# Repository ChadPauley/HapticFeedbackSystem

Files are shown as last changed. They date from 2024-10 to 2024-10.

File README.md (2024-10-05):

The purpose of this directory is to store PCB work and documentation on my first PCB design that was developed and sent to a fab house. While working on a team, I was tasked with designing the PCB layout for a Carrier Board that houses a CM4 module.
There are three versions of the PCB as we discovered issues and misleading information in the CM4 documentation such as camera pin layout. The final version worked and is in the primary CAD and schematic directory.

Version 2:
I2C lines for CAM1 are used for CAM0 which makes the camera a little finicky.

Version 3:
V3 fixes the issue with the camera and acts as a more ideal PCB.
--------------------------------------------------------------------------

After this project I have begun to focus more on the KiCAD software to design PCB fabs as a hobby due to the limitations of EAGLE only allowing 2 layers for the free version.

--------------------------------------------------------------------------
Real Fab Shape/Size:
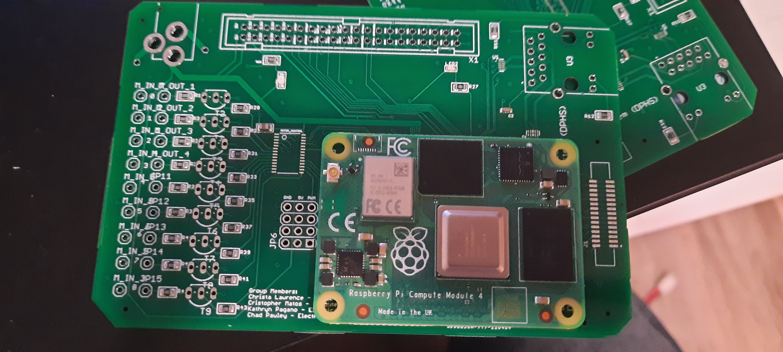
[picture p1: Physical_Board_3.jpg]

--------------------------------------------------------------------------
CAD Layout:
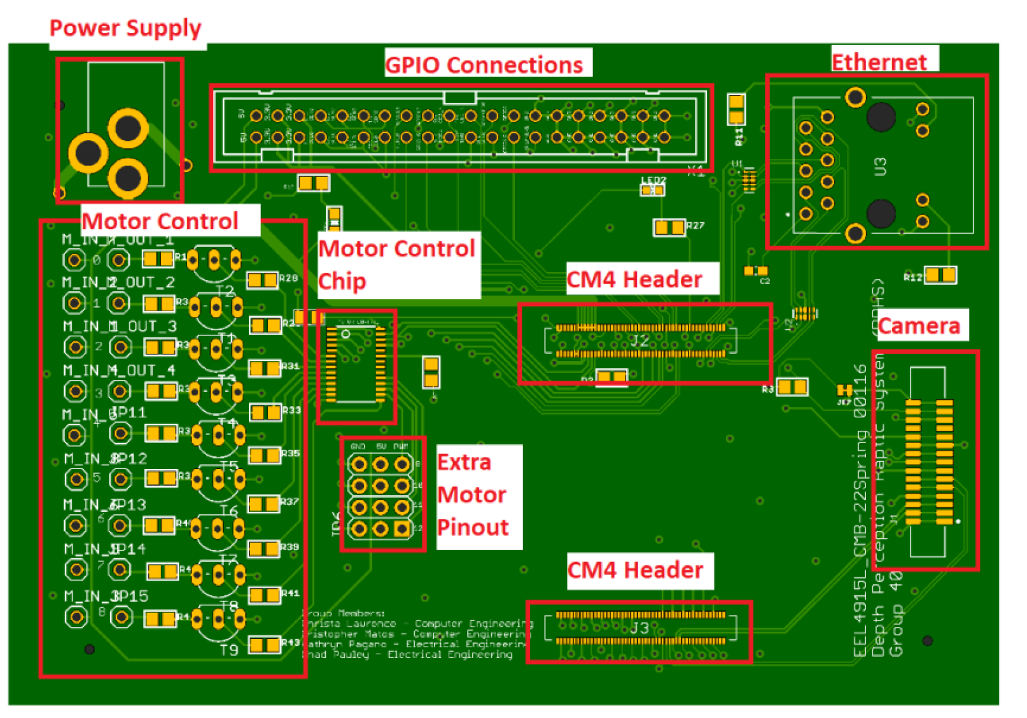
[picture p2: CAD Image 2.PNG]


--------------------------------------------------------------------------
Net paths:
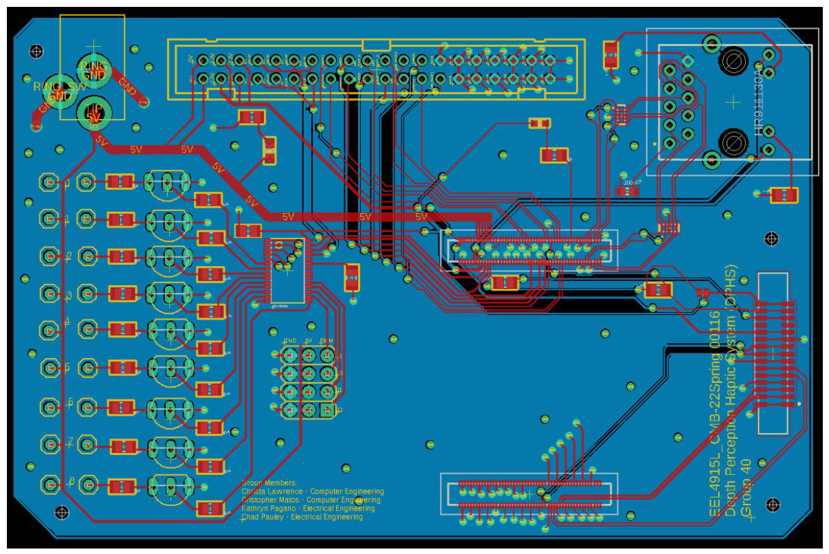
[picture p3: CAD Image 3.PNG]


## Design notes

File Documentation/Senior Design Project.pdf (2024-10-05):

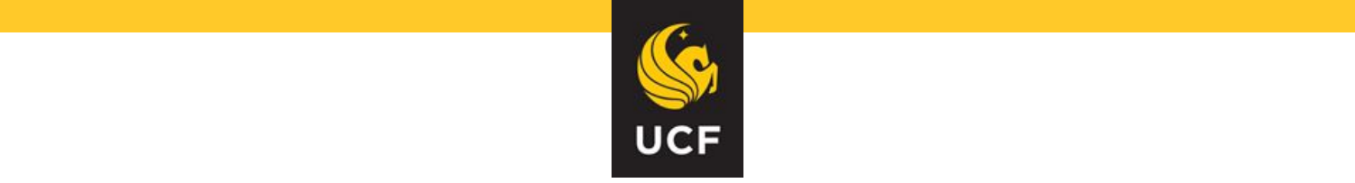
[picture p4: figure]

# Depth Perception Haptic System

# Group 40

## Christa Lawrence CpE Cristopher Matos CpE, Psych Kathryn Pagano EE Chad Pauley EE

# Outline

## - Goals and Requirements

## - Hardware Discussion and Component Considerations

## - Software Discussion

## - Successes and Difficulties

## - Administrative Details

# Goals

## - Wearable device that allows for hands-free navigation of indoor and outdoor

## spaces for people with impared vision

## - In particular:

- Avoid large obstacles (e.g., walls, poles, trash cans)

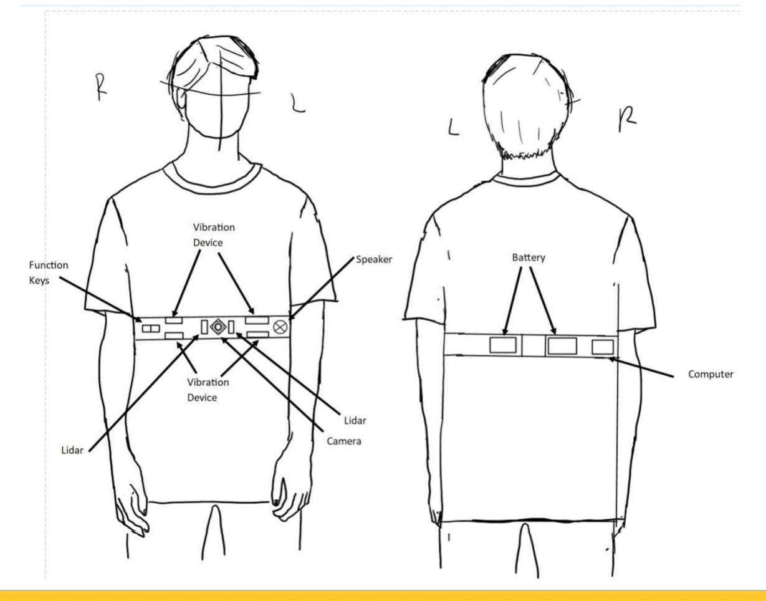
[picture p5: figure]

- Properly respond to sidewalk curbs

# Requirement Specifications

Statement | Description | Value | Unit
Lightweight | Total weight of electronics, housings, and cloth. | < 10 | lb
Compact | Thickness along all axes normal to the body. | < 2 | in
Full Range of Motion (ROM) | ROM of shoulder joints before and after putting on device. | < 10 | % diff
Large Buttons | Surface area large enough to contain braille. | > 0.7 | in²
Long Lasting, Rechargeable Battery | Time from full charge to depletion at 80% feedback level and all sensors active. | > 4 | hrs
Haptic feedback that encodes distance | Provides a relative indication of distance (via feedback intensity) of arbitrarily shaped objects visible to the camera over a discrete range of intensities (including zero). | ≥ 3 | ct
Alert to proximal objects | Objects near the device trigger an unambiguous alert. | < 3 | ft
Quick Response Time | Time it takes for the device to send a haptic response from
a spontaneously appearing obstacle.

< 900 ms

# Goals

Category | Goals
Physical Attributes | Lightweight, compact, durable
Usage & Maintenance | Responsive, rechargeable, long battery life, full range of motion (ROM)
User Interface | Simple, accessible, quick to learn
General Navigation | Encode distance and location of obstacles, alert to emergencies
Outdoor Navigation | Detect and describe curb presence, orientation, and magnitude

# Solution Approach - Obstacle Avoidance

## - Combine computer vision with LiDAR to map objects in the environment to

## the user’s body via haptic (vibration) feedback

- Minimizes # of sensors, maximizes input data

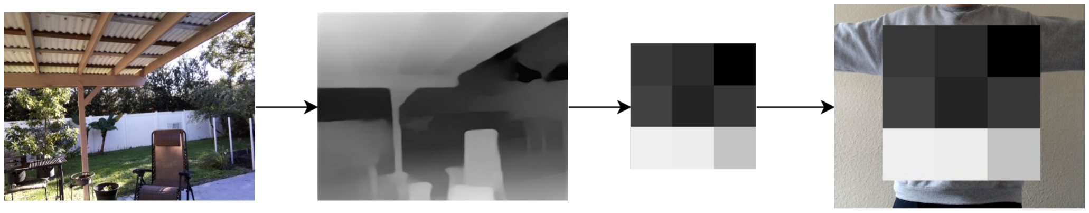
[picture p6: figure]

# Overall Block Diagram

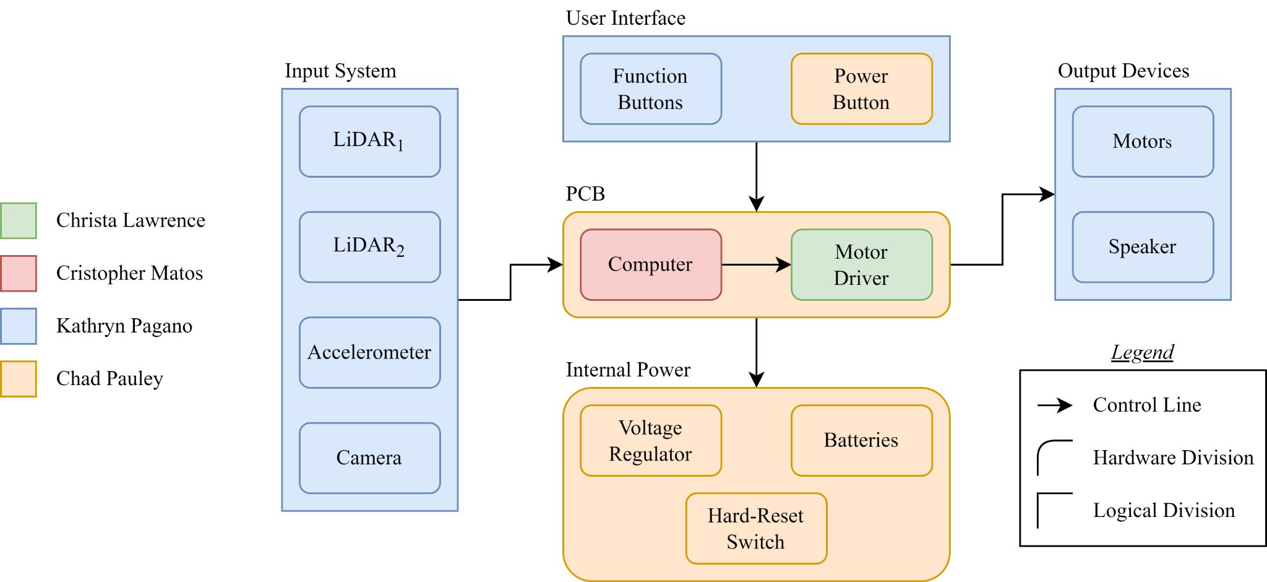
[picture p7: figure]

# Hardware Design Approach

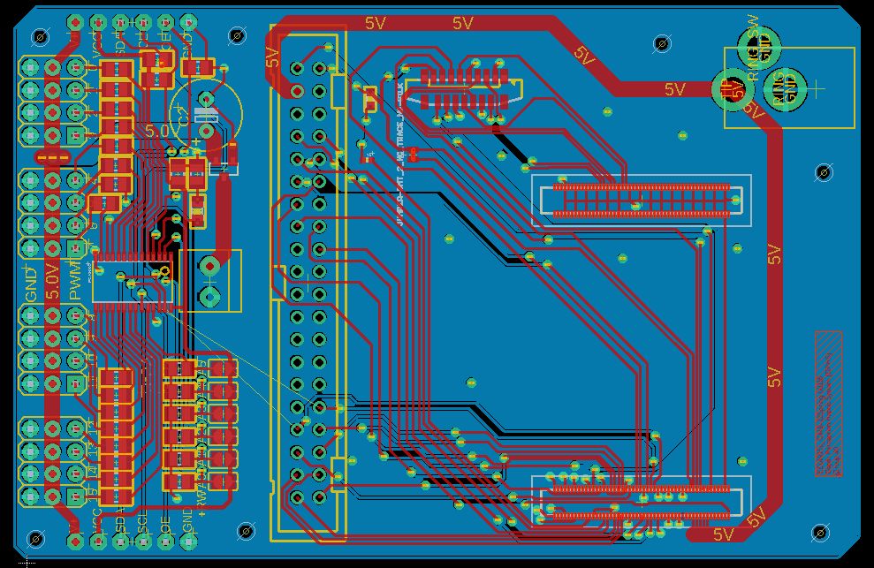
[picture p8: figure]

## Design Considerations

## - Minimize power consumption - Low resolution output - Minimize number of sensor units while

maximizing input data (CV + LiDAR),

## - Ensuring all clock and input data is coherent - Enough outputs to ensure future development and testing potential

Always plan to make a prototype, because you’ll end up building one anyway

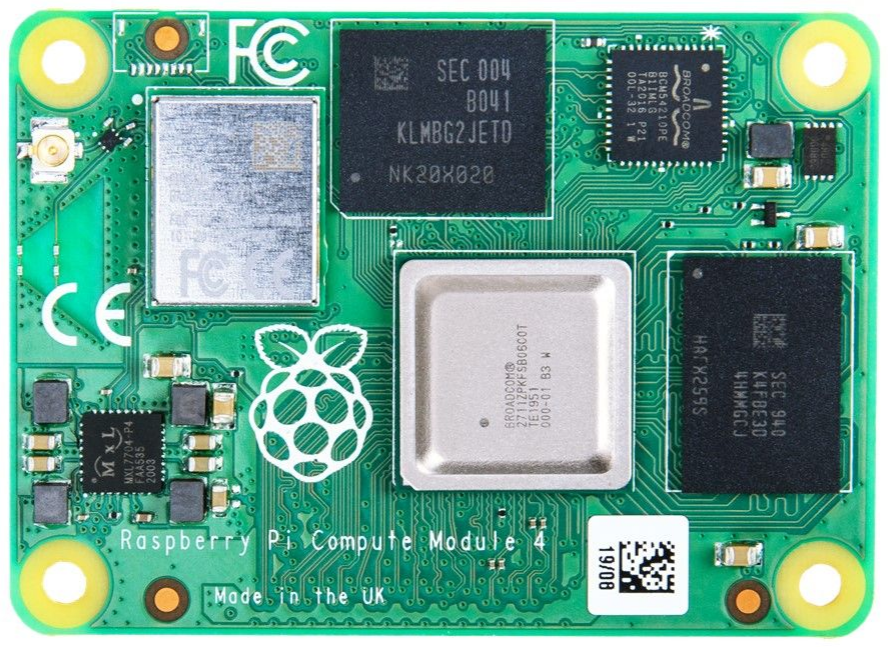
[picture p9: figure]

# Major Component Considerations

## - Raspberry Pi Compute Module 4 (CM4)

- Price
- Hardware independence
■ Entire project run on ARM CPU (and integrated GPU)
- Required RAM and embedded memory
- Availability of schematics
- Ability to modify carryout board
- GPIO availability (up to 5x UART, 5x I2C, 1x SDIO, 1 PCM, 2x PWM, 3x GPCLK, two MIPI CSI channels and multiple voltage output lanes including 3.3V and 1.8V)

# Raspberry Pi Camera

Model:Raspberry Pi Camera Module 2 Resolution
- 8-megapixel
- 3280 x 2464 still frame
Video mode
- 1080p30, 720p60, 480p90
Price
- $25.00
Board size
- 23.86 x 25 x 9mm
Onboard processor
- No

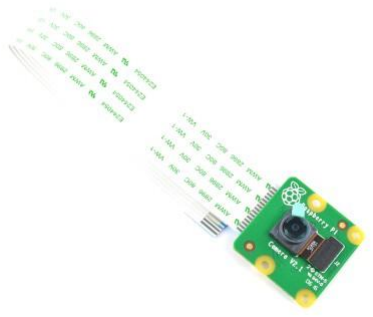
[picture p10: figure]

The camera module is incredibly small and can easily be concealed.
This camera is compatible with the Raspberry Pi board and can be connected using either a 15 pin connector or 22 pin adapter ribbon to work with the board.
It uses the Camera Serial Interface Type 2 (CSI-2).
Software Controlled directly by board, no special drivers needed.

# PCB Housing

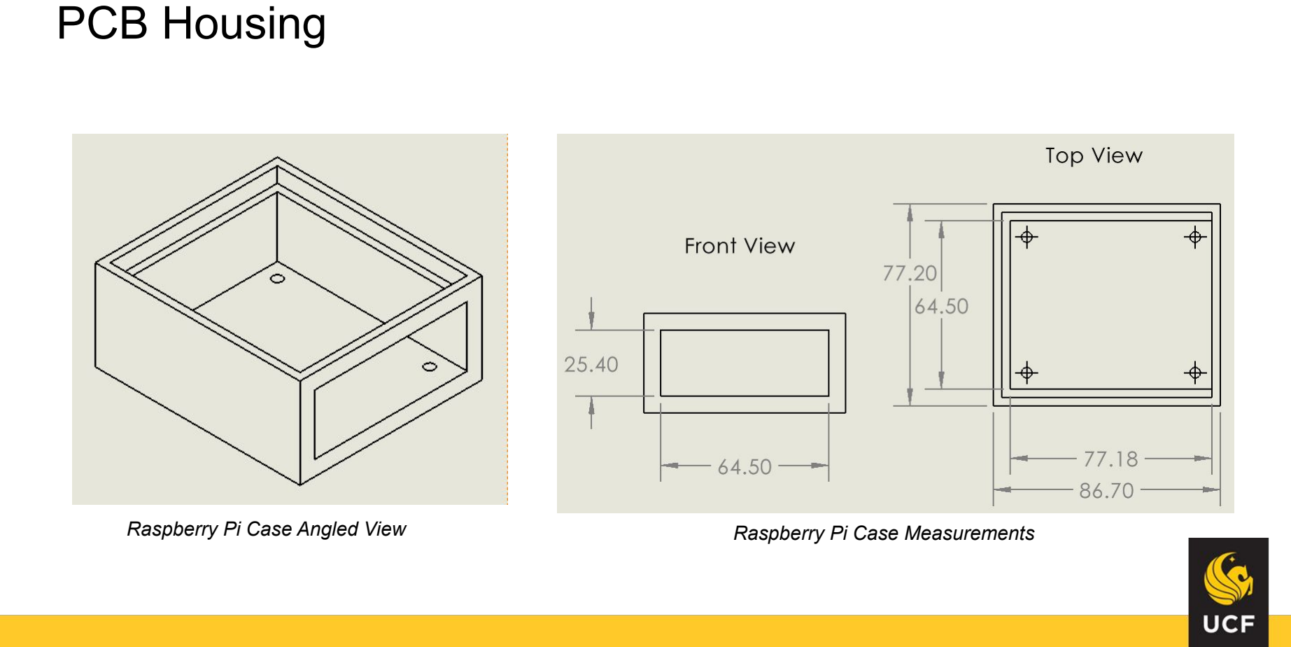
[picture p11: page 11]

Raspberry Pi Case Angled View | Raspberry Pi Case Measurements

# Raspberry Pi Camera Case

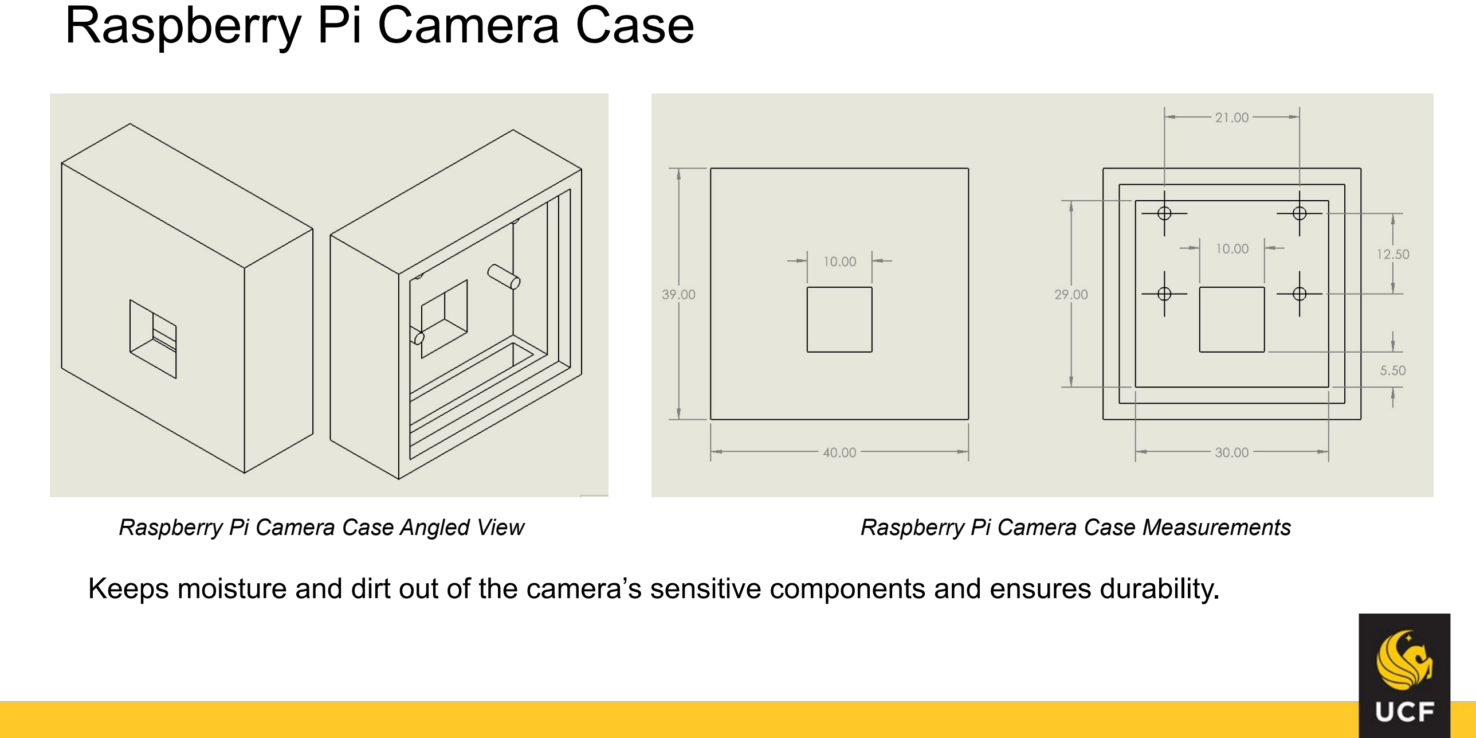
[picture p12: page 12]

Keeps moisture and dirt out of the camera’s sensitive components and ensures durability.

Raspberry Pi Camera Case Angled View | Raspberry Pi Camera Case Measurements

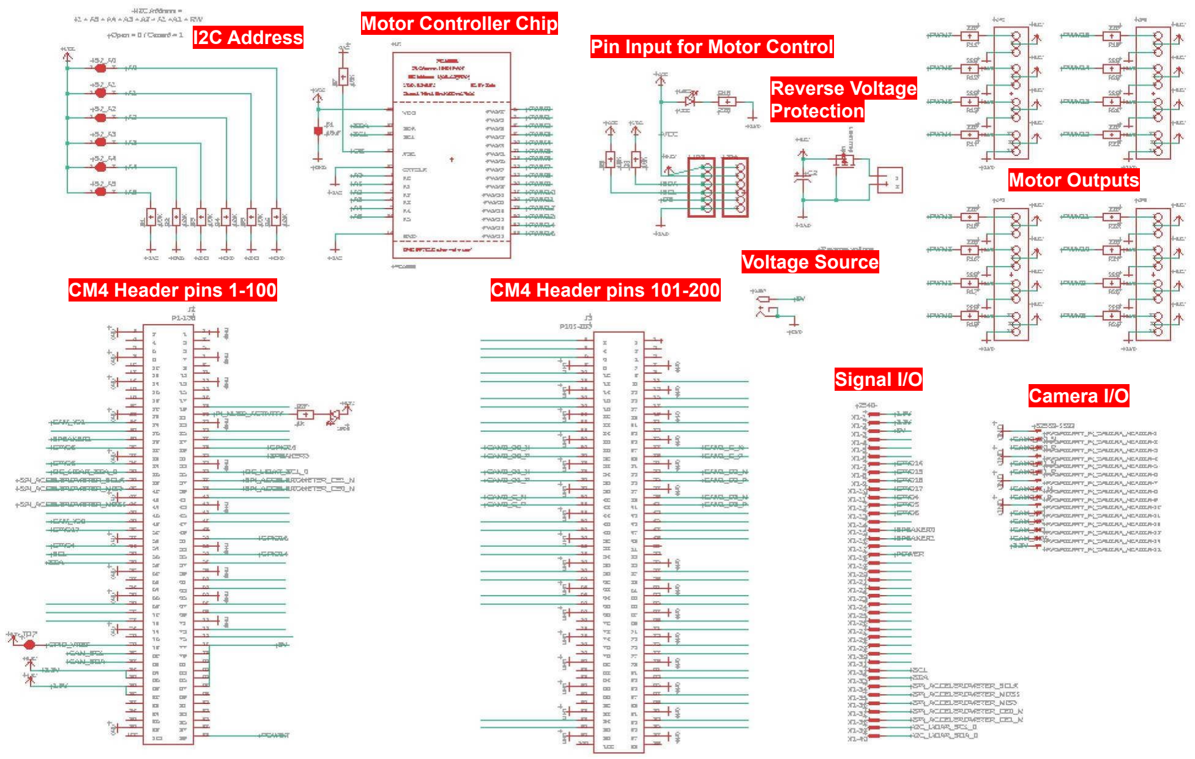
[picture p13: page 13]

Motor Controller Chip I2C Address | Pin Input for Motor Control

Voltage Source

Reverse Voltage
Protection

Motor Outputs

CM4 Header pins 1-100 | CM4 Header pins 101-200

Signal I/O
Camera I/O

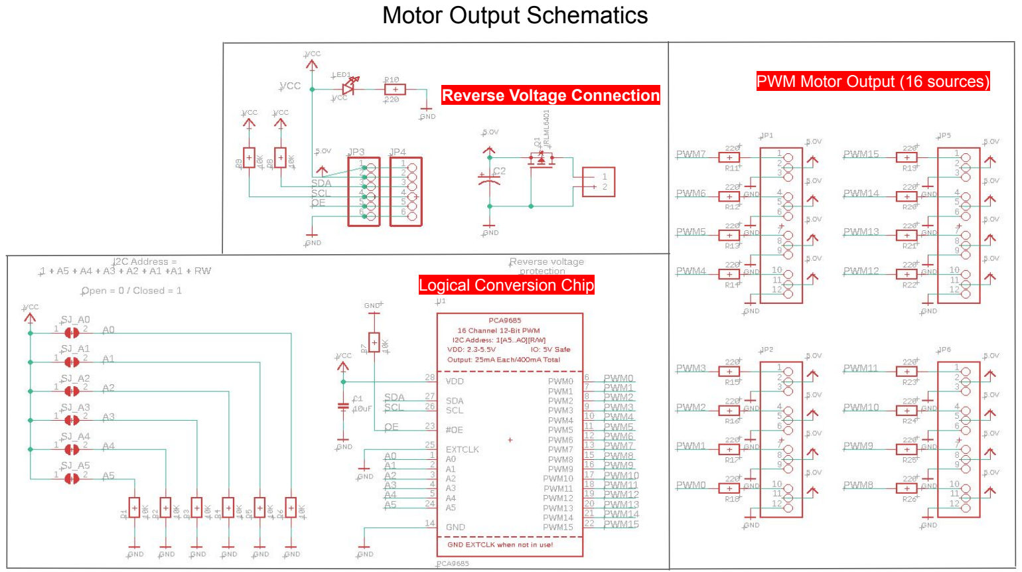
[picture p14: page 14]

Logical Conversion Chip

PWM Motor Output (16 sources) Reverse Voltage Connection

Motor Output Schematics

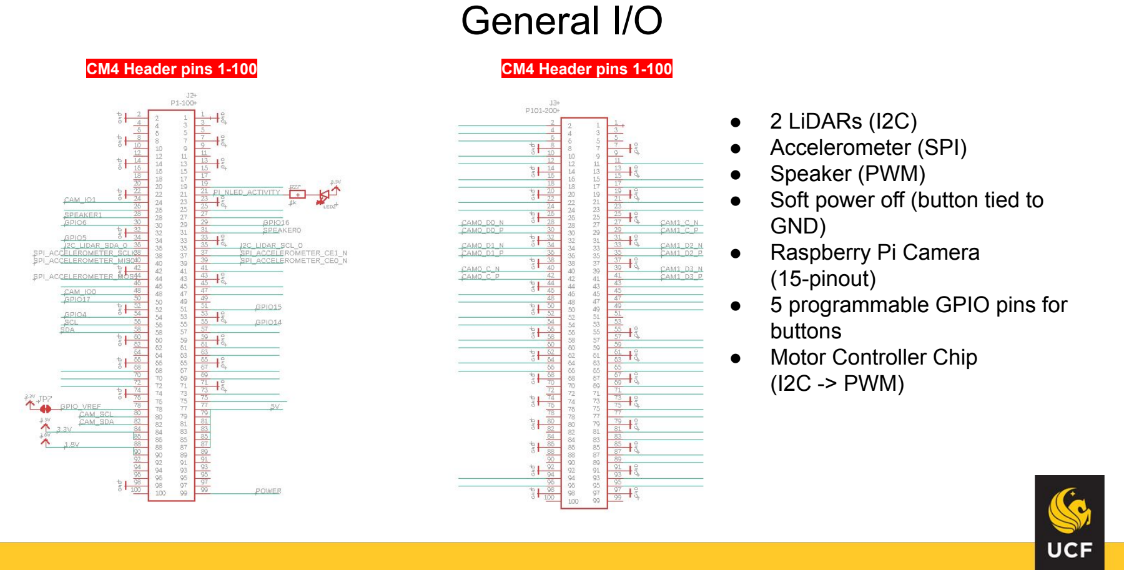
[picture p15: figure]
General I/O; ● 2 LiDARs (I2C) ● Accelerometer (SPI) ● Speaker (PWM) ● Soft power off (button tied to GND) ● Raspberry Pi Camera (15-pinout) ● 5 programmable GPIO pins for buttons ● Motor Controller Chip (I2C -> PWM)

CM4 Header pins 1-100 | CM4 Header pins 1-100

# Board layout

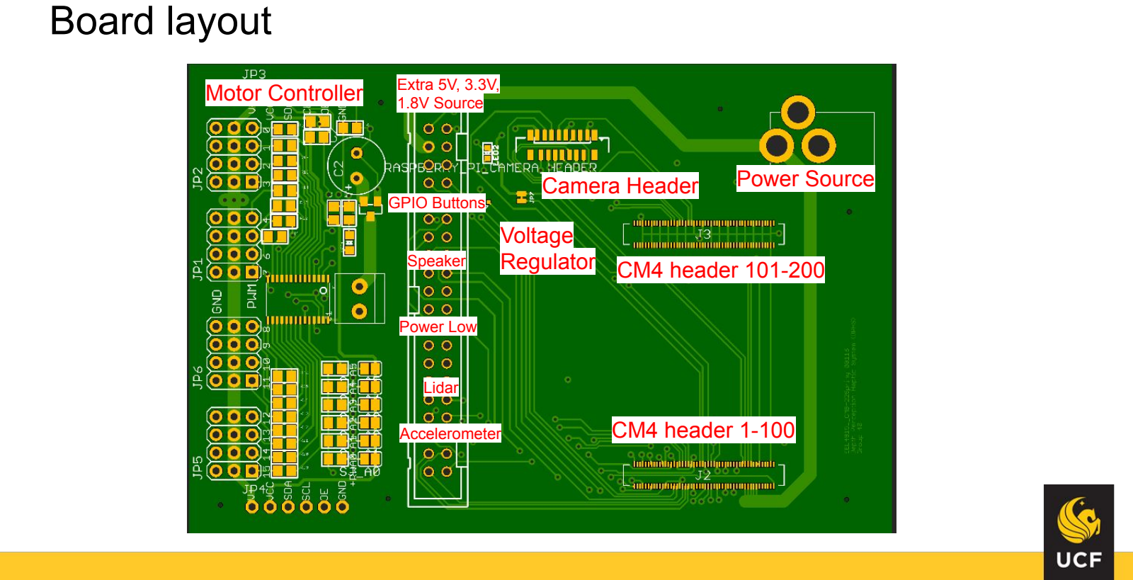
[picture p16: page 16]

Power Source

CM4 header 101-200

CM4 header 1-100

Camera Header

Voltage
Regulator

Motor Controller Extra 5V, 3.3V, 1.8V Source

GPIO Buttons

Speaker

Power Low

Lidar

Accelerometer

# 5 Programmable Buttons

## 1) Resting mode 2) Reset device due to error 3) Pathway Finder 4) Lower level of vibration 5) Increase level of vibration

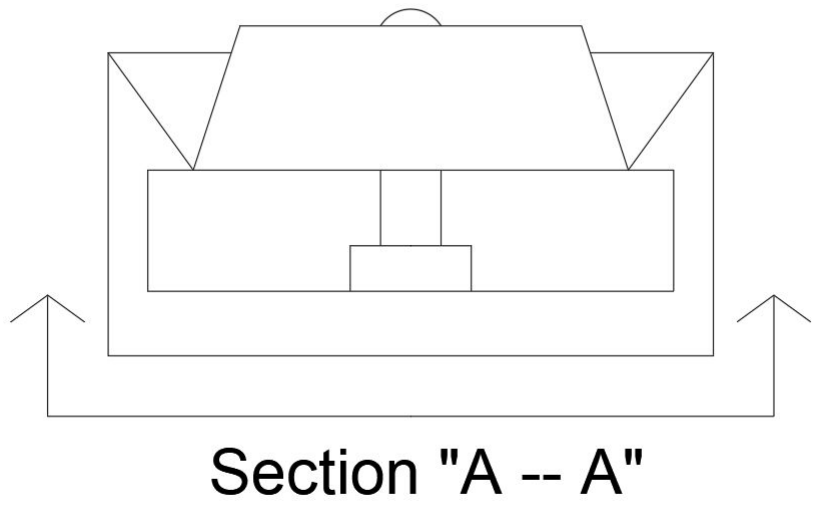
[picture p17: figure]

Button Cross-section

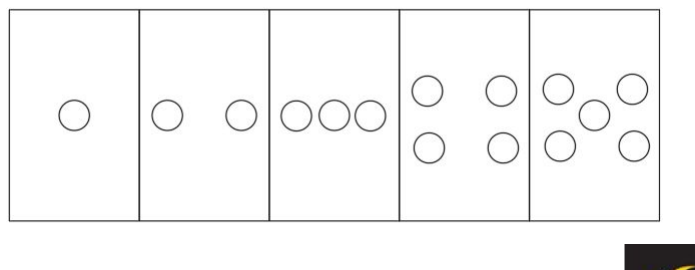
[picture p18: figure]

Button Domino Pattern

# Three Levels of Power Control

## - Idle Power Off (Software Controlled)

- Controlled by accelerometer input value and determination by CM4; the device will go into a resting mode reducing power usage to a minimal amount (around 8mA).

## - Button Power Off (Software Controlled)

- Button connected to GPIO GLOBAL_EN set driven low sets device to minimum power usage (around 15μA).

## - Switch Power Off (Hardware Controlled)

- Physical switch between the batteries and voltage regulator to allow the batteries and device to maintain longevity as well as function as hard reset for any potential errors.

# Voltage Regulator

## Batteries will be wired in parallel to provide the longest battery longevity possible

and allowing the device to maintain a steady current in the device for any needs.

## Mounted separately to batteries to have 5V source instead of 9V+. This prevents the user from getting shocked or burned by the device when the user is sweating

and the overall concern of the wear and tear of the device.

## A TAMAYA plug or Barrel Power Jack will be used to charge the device (as shown

below). User preference will be noted in a future study.

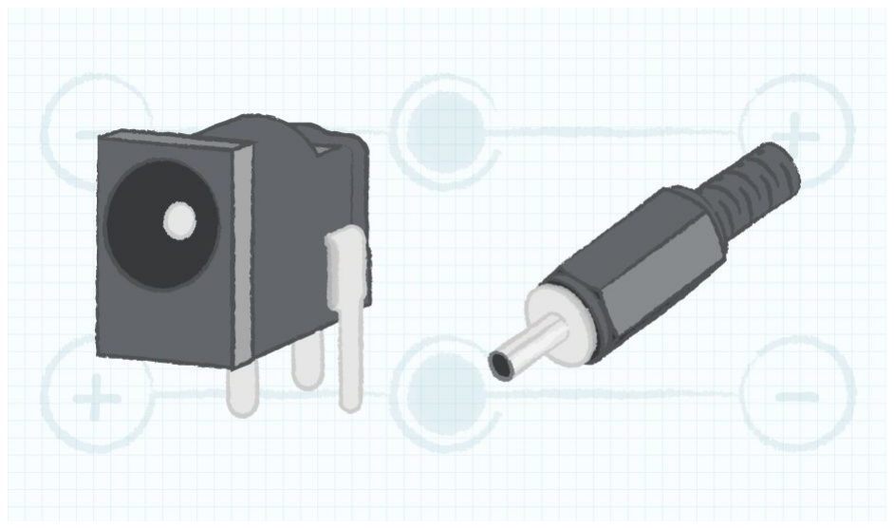
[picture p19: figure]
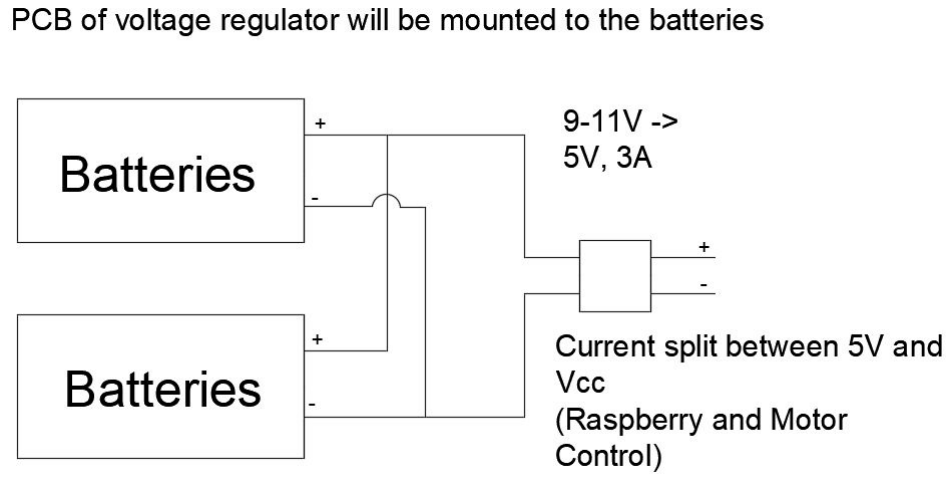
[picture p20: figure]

# Power Considerations

- Battery must be able to supply 3A with a voltage source between 5V and 30V.
- Due to design constraints in creating a power bus; the power for the CM4 and PWM motor control are differentiated as a primary 5V pin and VCC pin respectively on the board to evenly split current and effectively half the needed width for the bus channels on the PCB.

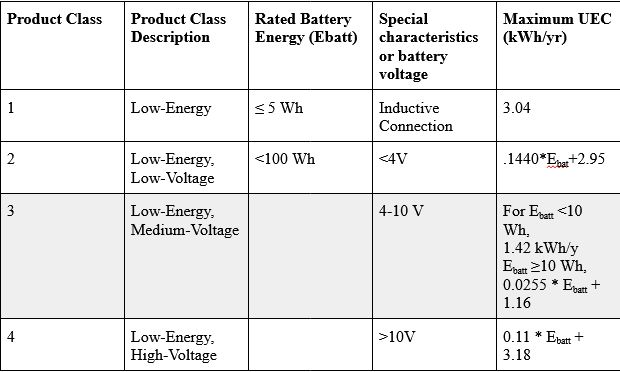
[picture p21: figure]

Electronic Code of Federal Regulations
- The device must be less than or equal to the maximum unit of energy consumption (UEC) for the appropriate product class and battery rating

# Hardware Design Changes Made Over Time

- Removal of HDMI interface as later noted as unnecessary and to reduce size of PCB - Removal of SD memory storage due to the need for more GPIO pins - Removal of voltage regulator chip on primary PCB board due to concern of electric shock - Change from using PWM with MOSFET connection which would control voltage of haptic motors with duty cycle to a direct connection with a simple diode and capacitor controlled by the programmable values set by analog

# Software Block Diagram

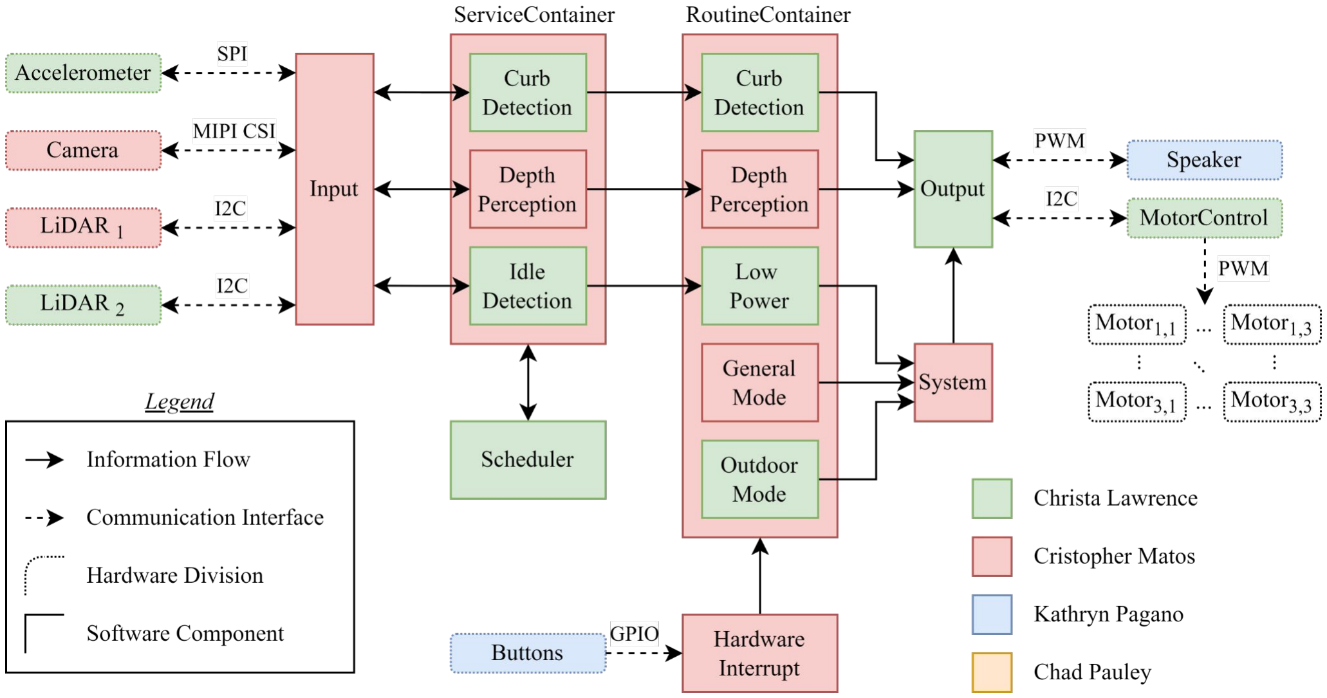
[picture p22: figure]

# Depth Sensing Approach

## - Problem: Need distances of objects located in front of the user

- Existing products use:
■ | Multiple distance sensors placed along body
■ | One distance sensor, actively manipulated by user
- Conflicts with our goals:
■ | Few sensors (For full ROM and comfort)
■ | Hands-free operation

## - Solution: Combine computer vision (CV) with LiDAR to estimate depth

# Depth Sensing Approach Motivation

## - Explosion of research and development in monocular depth estimation for mobile devices (Ignatov et al., 2021)

- Some models (including MIT Licensed) already exist online

## - Prospect of combining depth inferencing with LiDAR

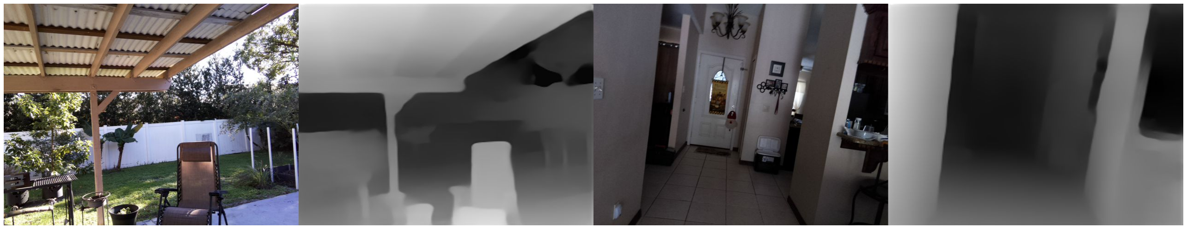
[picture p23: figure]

## Inference using Intel’s Midas/v2_1_small on TensorFlow Lite

# Depth Sensing Procedure

## 1. Use CV to create a depth map of the space in front of the user

a. LiDAR used to approximate true values

## 2. Divide map into regions 3. Find one representative value per region 4. Set motor intensity based on value

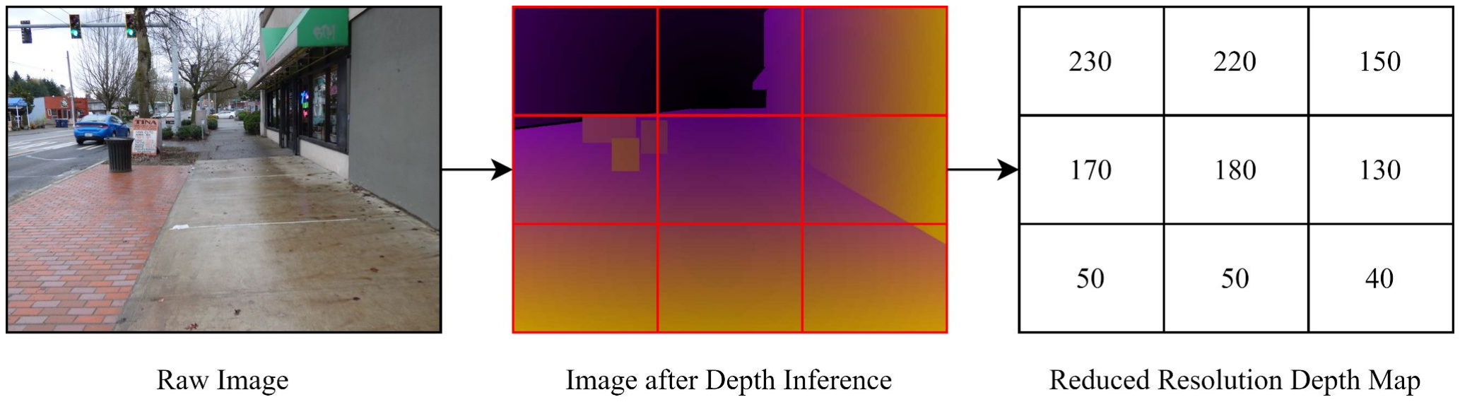
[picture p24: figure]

## Raw Image sourced from (SDOT, 2015)

# Depth Sensing Problems

## - Inference time (exposed chip, no fan, 21℃, all on CPU)

- Arithmetic Mean: 912 ms, Sample Std Dev: 11 ms, Maximum: 967 ms

## - Temperature

- Throttle temperature reached within 700 iterations (~ 12 mins)

# Depth Sensing Solutions Considered

## - NVIDIA Jetson Nano?

- 2x Price
- Research shows ARM CPU is all that is needed for fast depth estimation

## - Overclocking CPU?

- Energy consumption and device lifetime
- Intended to operate over several hours

## - Start from scratch?

- Lack time and resources to train robust model
- Models tend to underperform on datasets not used in training/validation (Ranftl et al., 2020)

## - Another pretrained model?

- MIT Licensed models tested significantly slower (seconds)

# Depth Sensing Solutions

## - Quantization and Open-Source Optimization tools - Knowledge distillation

- Use representative dataset to train new model with Midas as teacher
- Some approaches show inference time as low as 97 ms (Zhang et al., 2021)

## - On-board GPU acceleration

- Some libraries available (beatmup, ncnn)

## - Introduce a heat sink - Worst-case scenario: Forfeit robustness for speed

- Train new model on a subset of datasets

# Other Software

## - Curb Detection

- Use a LiDAR unit angled downward to determine magnitude and direction of curbs

## - Idle Detection

- Accelerometer used to estimate velocity of user

## - Speaker announces mode changes, power-on, power-off, and emergencies - Buttons control mode of system

# Successes and Difficulties

## Part Availability (Voltage Regulators)

## Shipping Dates

## PCB arrangement on 2-layer design

## CV Runtime Reduction

# Budget

Item Type | Quantity | Actual Cost | Description
LiDAR | 2 | $59.99 | Garmin LiDAR
Accelerometer | 1 | $18.95 | ADXL345
Camera | 1 | $25 | Raspberry Pi Camera
Speaker | 1 | $10.69 | MakerHawk Speaker
Haptic feedback | Set acquirement (20) | $16.04 | Tatoko flat coin motors
Compute Module | 1 | $65 | Raspberry Pi Compute 4 Module 4GB
Shipping | | $37.93 | Shipping on parts
Current Total (As of 11/19/2021) | | =293.60

# Progress by Category

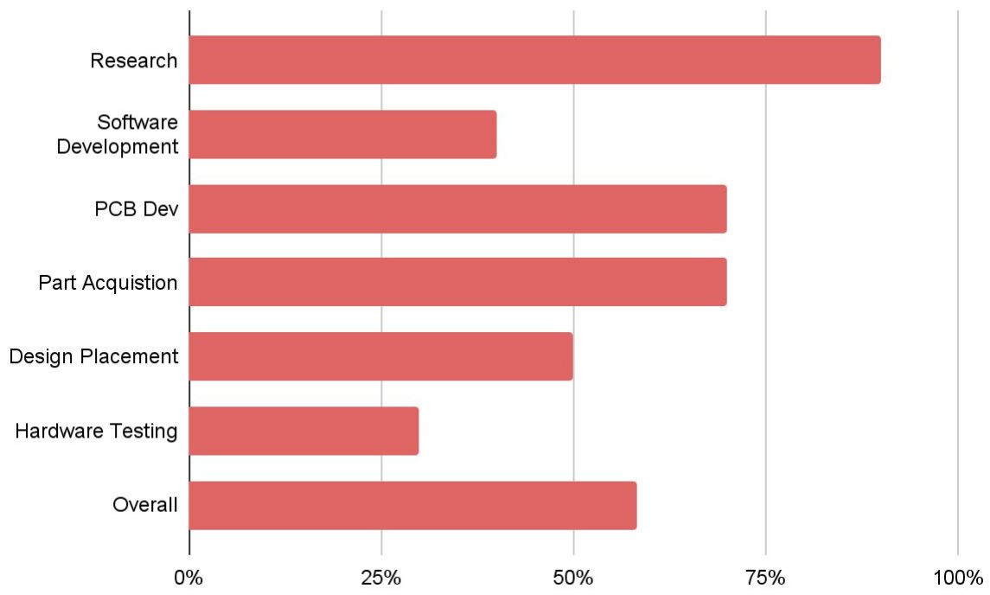
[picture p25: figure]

# Steps Toward Completion - Software

Step | Deadline
Faster (< 900 ms) depth estimation on RPi4 Faster (< 500 ms) depth estimation on RPi4 | February 27 March 13
UI, general mode, outdoor mode code complete | March 6
Idle detection, lower power mode, speaker code complete | March 20
Initial software testing and refactoring complete | April 3
Final software testing and optimization complete | April 10

# Steps Toward Completion - Hardware

Step | Deadline
User interface constructed, tested All devices integrated in development environment | March 6
PCB final version submitted | March 20
All devices integrated in fully functional prototype | April 3
Assembly of final project complete | April 10

# Milestones

Milestone | Due Date
Basic end-to-end functionality (CV + LiDAR integration, motor output) | February 25
Full initial prototype (buttons, all functionalities, motor output, improved CV performance, battery connection) | March 13
Final prototype complete (fully functional vest) | April 3
Final testing and optimization complete | April 10

# Progress Photos

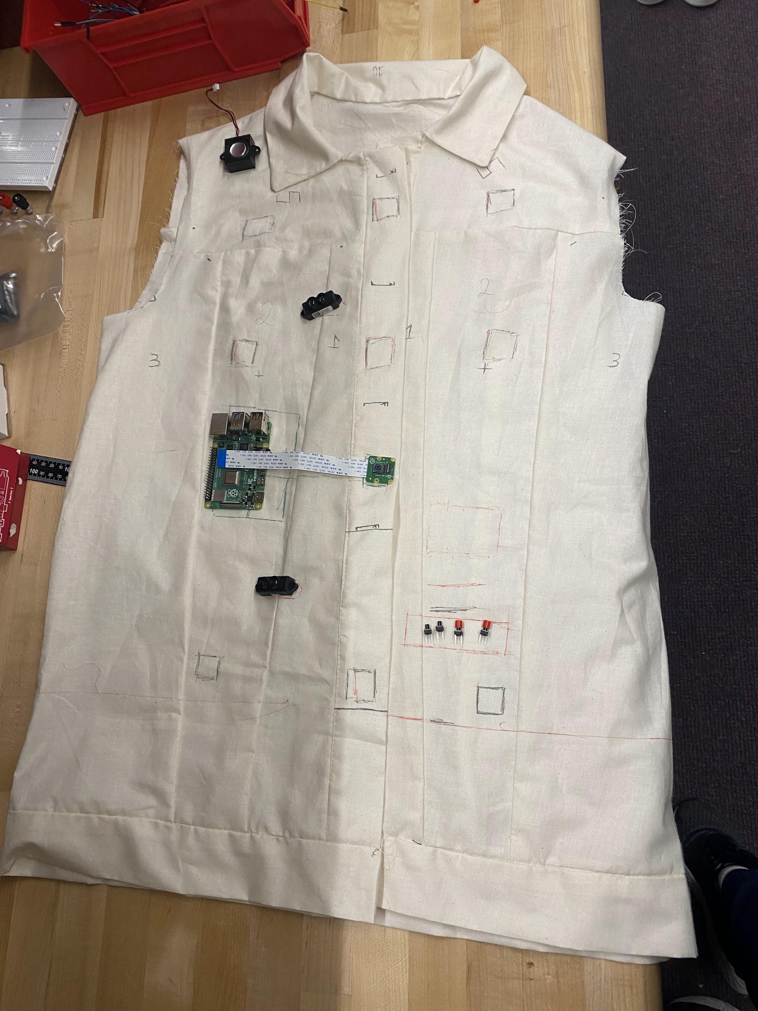
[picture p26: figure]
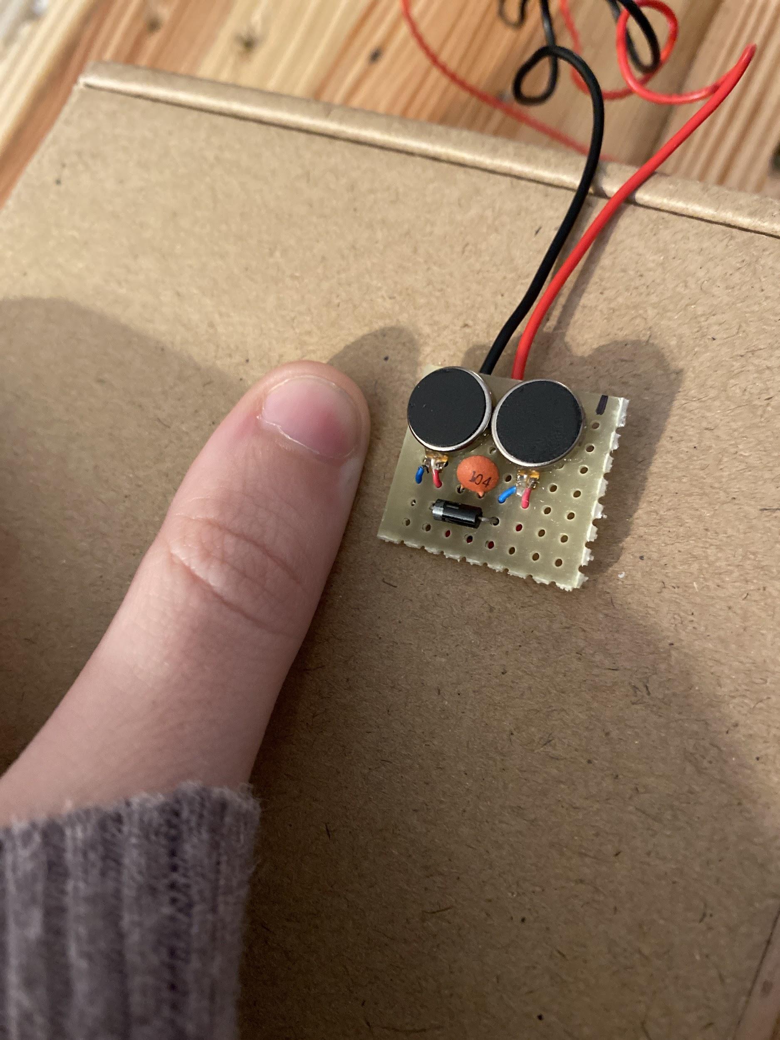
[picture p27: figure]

# References

Allan, Alasdair. “Benchmarking TensorFlow Lite on the New Raspberry Pi 4, Model B.” Hackster.io, 2019, https://www.hackster.io/news/benchmarking-tensorflow-lite-on-the-new-raspberry-pi-4- model-b-3fd859d05b98.

Ignatov, Andrey, et al. “Fast and Accurate Single-Image Depth Estimation on Mobile Devices, Mobile AI 2021 Challenge: Report.” ArXiv, 17 May 2021, https://arxiv.org/pdf/2105.08630.pdf.

Ranftl, Rene, et al. “Towards Robust Monocular Depth Estimation: Mixing Datasets for Zero-shot Cross-dataset Transfer.” IEEE Transactions on Pattern Analysis and Machine Intelligence, 2020, https://arxiv.org/abs/1907.01341.

SDOT Photos. “Columbia City Sidewalk Repair Project.” flickr, 16 Dec. 2015, https://www.flickr.com/photos/sdot_photos/23168490614. Image. Used in its resized form, and colored over with gradients to depict depth. Licensed under CC BY-NC 2.0.

Zhang, Ziyu, et al. “A Simple Baseline for Fast and Accurate Depth Estimation on Mobile Devices.” 2021 IEEE/CVF Conference on Computer Vision and Pattern Recognition Workshops (CVPRW), 2021, https://openaccess.thecvf.com/content/CVPR2021W/MAI/papers/Zhang_A_Simple_Baseline_for_Fast_and_Accurate_Depth_Estimation_on_CVPRW_2021_paper.pdf.

# Questions?

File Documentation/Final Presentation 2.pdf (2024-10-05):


# Depth Perception Haptic System

# Group 40

## Christa Lawrence CpE Cristopher Matos CpE, Psych Kathryn Pagano EE Chad Pauley EE

# Outline

## - Project Objective

## - Requirements

## - Software Discussion

## - Hardware Discussion

## - Administrative Details

## - Testing

## - Demonstration

# Project Objective

## The Depth Perception Haptic System

## is a wearable device that allows for

## hands-free navigation of indoor and

## outdoor spaces

# Goals

Category | Goals
Physical Attributes | Lightweight, compact, durable
Usage & Maintenance | Responsive, rechargeable, long battery life, full range of motion (ROM)
User Interface | Simple, accessible, quick to learn
General Navigation | Encode distance and location of obstacles, alert to emergencies
Outdoor Navigation | Detect and describe curb presence, orientation, and magnitude

# Requirement Specifications

Statement | Description | Value | Unit
Lightweight | Total weight of electronics, housings, and cloth. | < 10 | lb
Compact | Thickness along all axes normal to the body. | < 2 | in
Full Range of Motion (ROM) | ROM of shoulder joints before and after putting on device. | < 10 | % diff
Large Buttons | Surface area large enough to contain braille. | > 0.25 | in²
Long Lasting, Rechargeable Battery | Time from full charge to depletion at 80% feedback level and all sensors active. | > 6 | hrs
Haptic feedback that encodes distance | Provides a relative indication of distance (via feedback intensity) of arbitrarily shaped objects visible to the camera over a discrete range of intensities (including zero). | ≥ 3 | ct
Alert to proximal objects | Objects near the device trigger an unambiguous alert. | < 3 | ft
Quick Response Time | Time it takes for the device to send a haptic response from
a spontaneously appearing obstacle.

< 900 ms

# Solution Approach - Obstacle Avoidance

## - Combine computer vision with LiDAR to map objects in the environment to

## the user’s body via haptic (vibration) feedback

- Minimizes # of sensors, maximizes input data


# Overall Block Diagram


# Hardware Design Approach


## Design Considerations

## - Minimize power consumption - Low resolution output - Minimize number of sensor units while

maximizing input data (CV + LiDAR),

## - Ensuring all clock and input data is coherent - Enough outputs to ensure future development and testing potential

Always plan to make a prototype, because you’ll end up building one anyway


# Major Component Considerations

## - Raspberry Pi Compute Module 4 (CM4)

- Price
- Hardware independence
■ Entire project run on ARM CPU (and integrated GPU)
- Required RAM and embedded memory
- Availability of schematics
- Ability to modify carryout board
- GPIO availability (up to 5x UART, 5x I2C, 1x SDIO, 1 PCM, 2x PWM, 3x GPCLK, two MIPI CSI channels and multiple voltage output lanes including 3.3V and 1.8V)

# Raspberry Pi Camera

Model:Raspberry Pi Camera Module 2 Resolution
- 8-megapixel
- 3280 x 2464 still frame
Video mode
- 1080p30, 720p60, 480p90
Price
- $25.00
Board size
- 23.86 x 25 x 9mm
Onboard processor
- No
The camera module is incredibly small and can easily be concealed.
This camera is compatible with the Raspberry Pi board and can be connected using either a 15 pin connector or 22 pin adapter ribbon to work with the board.
It uses the Camera Serial Interface Type 2 (CSI-2).
Software Controlled directly by board, no special drivers needed.

# PCB Housing


Raspberry Pi Case Angled View | Raspberry Pi Case Approx. Measurements

# Raspberry Pi Camera Case


Keeps moisture and dirt out of the camera’s sensitive components and ensures durability.

Raspberry Pi Camera Case | Raspberry Pi Camera Case Approx. Measurements


- | 2 LiDARs (I2C) ● | Speaker (PWM) ● | Soft power off (button tied to GND)
- | Raspberry Pi Camera (15-pinout) ● | 5 programmable GPIO pins for buttons ● | Motor Controller Chip (I2C -> PWM)

# Board layout


Power Source

CM4 header 101-200

CM4 header 1-100

Camera Header

Ethernet

Motor Controller

Extra 5V, 3.3V Source, buttons, LiDAR, Speaker

Power LED Activity LED

4 Programmable Buttons; 1) Outdoor Moode 2) Spare 3) Low Power Mode; 4) General Mode; Button Cross-section; Button Layout; On/ Off Switch; 1 Outdoor Moder; 2 Spare; 3 Low Power Mode; 4 General Mode

# Two Levels of Power Control

## - Button Power Off (Software Controlled)

- Button connected to GPIO GLOBAL_EN set driven low sets device to minimum power usage (around 15μA).

## - Switch Power Off (Hardware Controlled)

- Physical switch between the batteries and voltage regulator to allow the batteries and device to maintain longevity as well as function as hard reset for any potential errors.

# Voltage Regulator

## Mounted separately to batteries to have 5V source instead of 12V+

## A TAMAYA plug is used to charge the device (as shown below)

## Barrel Jack connects to the board


# Power Considerations

- Battery must be able to supply 3A with a voltage source between 5V and 30V.
- Due to design constraints in creating a power bus; the power for the CM4 and PWM motor control are differentiated as a primary 5V pin and VCC pin respectively on the board to evenly split current and effectively half the needed width for the bus channels on the PCB.


Electronic Code of Federal Regulations
- The device must be less than or equal to the maximum unit of energy consumption (UEC) for the appropriate product class and battery rating

# Power Considerations


# Hardware Design Changes Made Over Time

- Removal of HDMI interface as later noted as unnecessary and to reduce size of PCB - Removal of SD memory storage due to the need for more GPIO pins - Removal of voltage regulator chip on primary PCB board due to concern of electric shock - Change from using PWM with MOSFET connection which would control voltage of haptic motors with duty cycle to a direct connection with a simple diode and capacitor controlled by the programmable values set by analog - Addition of ethernet connector to PCB for troubleshooting

# Software Overview


# Depth Perception Approach

## - Problem: Need distances of objects located in front of the user

- Existing products use:
■ | Multiple distance sensors placed along body
■ | One distance sensor, actively manipulated by user
- Conflicts with our goals:
■ | Few sensors (For full ROM and comfort)
■ | Hands-free operation

## - Solution: Combine computer vision (CV) with LiDAR to estimate depth

# Approach Motivation

## - Explosion of research and development in monocular depth estimation for mobile devices (Ignatov et al., 2021)

- Some models (including MIT Licensed) already exist online

## - Prospect of combining depth inferencing with LiDAR

## Inference using Intel’s Midas/v2_1_small on TensorFlow Lite

# Depth Sensing Procedure

## 1. Use MiDaS to create a depth map of the space in front of the user 2. Divide map into regions 3. Find one representative value per region 4. Set motor intensity based on value


## Raw Image sourced from (SDOT, 2015)

# Representative Value and Motor Response

## 1. Subtract box filter 2. Clip 3. Discretize to N levels 4. Maxpool 5. Compare with previous

## Motor intensity varies linearly with estimated depth

## More complex response patterns likely require a greater time to learn

Input | MiDaS | Filtered
Clipped | Discretized | Maxpooled

# Latency Reduction and Accuracy Penalty

## - Alibaba MNN Framework with UINT8 quantized weights of MiDaS v2.1 Small

- Maximum inference time: 302 ms, 3.3 FPS
- 3.1x speedup from FP32 model on Tensorflow Lite
| TF Lite¹ | TF Lite w/ XNNPACK | MNN²
Floating Point Weights | T1 = 1,906 T2 = 1,213 T8 = 1,619 | 1,170 655 511 1,136 | 744 445 398 578
Int Quantized Weights³,4,5 | 1,111 670 468 1,249 | 1,106 682 467 1,179 | 901 486 454

T4

= 948

302

Maximum inference times (ms) for various thread counts Ti

. All benchmarks set to 5 warm up runs, 50 runs, VideoCore temp below 70.0 ℃. 1 Results from TF Lite linux arm benchmark tool
2 Results from MNN model benchmark tool
3 Weights quantized using RedWeb V1 dataset
4 INT8 quantized weights for TF Lite from default optimization tool
5 UINT8 quantized weights for MNN from the quantization tool. KL divergence for features, max absolute value for weights

# Latency Reduction and Accuracy Penalty

## - Minor reduction in accuracy when using UINT8 weights versus FP32

- Inference time greater priority than pixel-for-pixel accuracy
- Essential features preserved


FP32 | UINT8


# Curb Detection

○ Otherwise, step up

## - LiDAR angled downward to poll for changes in floor height - Maintains finite length queue which detects range changes over time

- If the index of the maximum of the curb is before the index of the minimum, step down

# Emergency Detection

## - Forward-facing LiDAR programmatically connected to motor device central to the chest

- Linear haptic response to distance detected by device

## - When the threshold distance (3 ft) is detected, the system will force all motors to vibrate until the obstacle is no longer present

- All motors 100% haptic feedback intensity at 5 Hz and 50% duty cycle

# Successes and Difficulties

## Part Availability (CM4 and Voltage Regulator)

## Shipping Dates

## PCB arrangement on 2-layer design

## CV Runtime Reduction

Budget | Item Type | Quantity | Actual Cost | Description
LiDAR | 2 | $60 | Garmin LiDAR
Accelerometer | 1 | $19 | ADXL345
Camera | 1 | $25 | Raspberry Pi Camera
Speaker | 1 | $11 | MakerHawk Speaker
Haptic feedback | Set acquirement (20) | $16 | Tatoko flat coin motors
Compute Module | 2 | $215 | Raspberry Pi Compute 4 Module 4GB (+Replacement)
Fabric | 1 | $25
Battery | 3 | $15 | 12V, 4800mAh
Misc. Electronics & Materials | | $100
Shipping | $37.93 | Shipping on parts
Current Total | =$576


# TESTING

# Testing Considerations

## - Fabric can muffle sounds and haptic feedback: Can the user hear the

## audible alerts and feel the haptic vibrations?

## - Can the user effectively avoid approaching obstacles?

## - How long does the battery actually last?

## - What is the voltage coming out of the regulator?

## - Do the lidars provide distance based alerts?

## - Do the buttons work?

## - Do we have a successful Field test?

# Hardware Testing


# Hardware Testing


# COMPONENT & REQUIREMENT TESTING

# FEEDBACK

# TESTING OBSERVATIONS

# FULL INTEGRATION FIELD TEST

# Requirement Specifications

Statement | Description | Value | Actual | Y/N | Unit
Lightweight | Total weight. | < 10 | 4.0 | Y | lb
Compact | Thickness along normal to the body. | < 2 | 1.8 | Y | in
Full Range of Motion (ROM) | ROM of shoulder joints. | < 10 | 0 | Y | % diff
Large Buttons | Surface area of buttons. | > 0.25 | 0.28 | Y | in²
Long Lasting | Time from full charge to depletion. | > 6 | 2.0 | N | hrs
Haptic feedback that encodes distance | Detectable feedback levels. | ≥ 3 | 8 | Y | ct
Alert to proximal objects | Objects near the device alert. | < 3 | 1.5 | Y | ft
Quick Response Time | Latency of computer vision. | < 900 | 302 | Y | ms

# References

Allan, Alasdair. “Benchmarking TensorFlow Lite on the New Raspberry Pi 4, Model B.” Hackster.io, 2019, https://www.hackster.io/news/benchmarking-tensorflow-lite-on-the-new-raspberry-pi-4- model-b-3fd859d05b98.

Ignatov, Andrey, et al. “Fast and Accurate Single-Image Depth Estimation on Mobile Devices, Mobile AI 2021 Challenge: Report.” ArXiv, 17 May 2021, https://arxiv.org/pdf/2105.08630.pdf.

Ranftl, Rene, et al. “Towards Robust Monocular Depth Estimation: Mixing Datasets for Zero-shot Cross-dataset Transfer.” IEEE Transactions on Pattern Analysis and Machine Intelligence, 2020, https://arxiv.org/abs/1907.01341.

SDOT Photos. “Columbia City Sidewalk Repair Project.” flickr, 16 Dec. 2015, https://www.flickr.com/photos/sdot_photos/23168490614. Image. Used in its resized form, and colored over with gradients to depict depth. Licensed under CC BY-NC 2.0.

Zhang, Ziyu, et al. “A Simple Baseline for Fast and Accurate Depth Estimation on Mobile Devices.” 2021 IEEE/CVF Conference on Computer Vision and Pattern Recognition Workshops (CVPRW), 2021, https://openaccess.thecvf.com/content/CVPR2021W/MAI/papers/Zhang_A_Simple_Baseline_for_Fast_and_Accurate_Depth_Estimation_on_CVPRW_2021_paper.pdf.

# Questions?

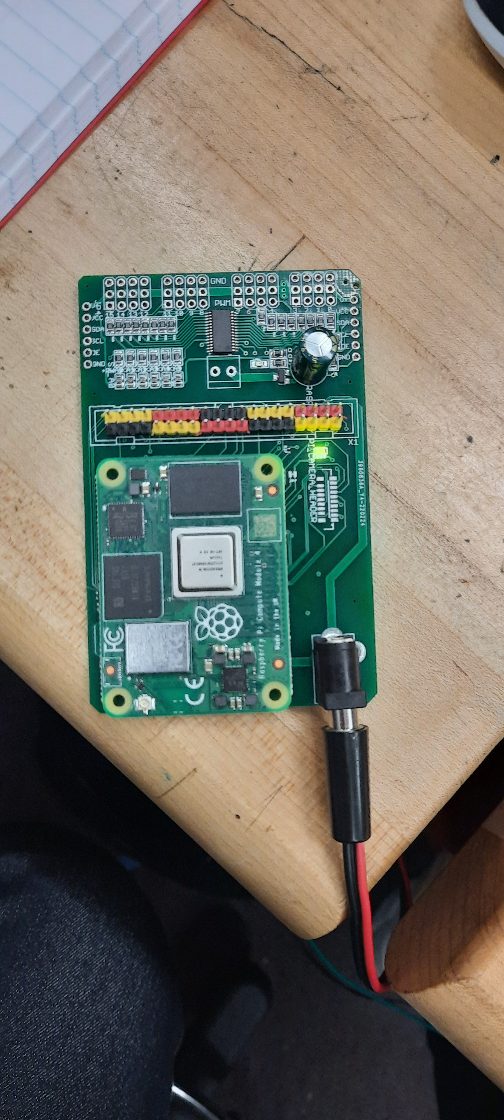
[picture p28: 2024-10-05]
Physical_Board_2.jpg

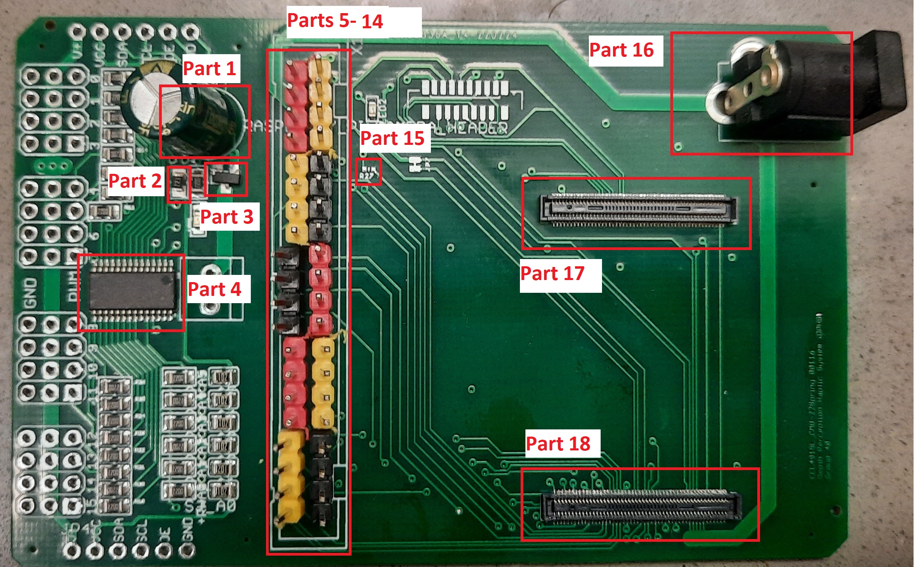
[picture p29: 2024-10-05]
Physical_Board_1.jpg

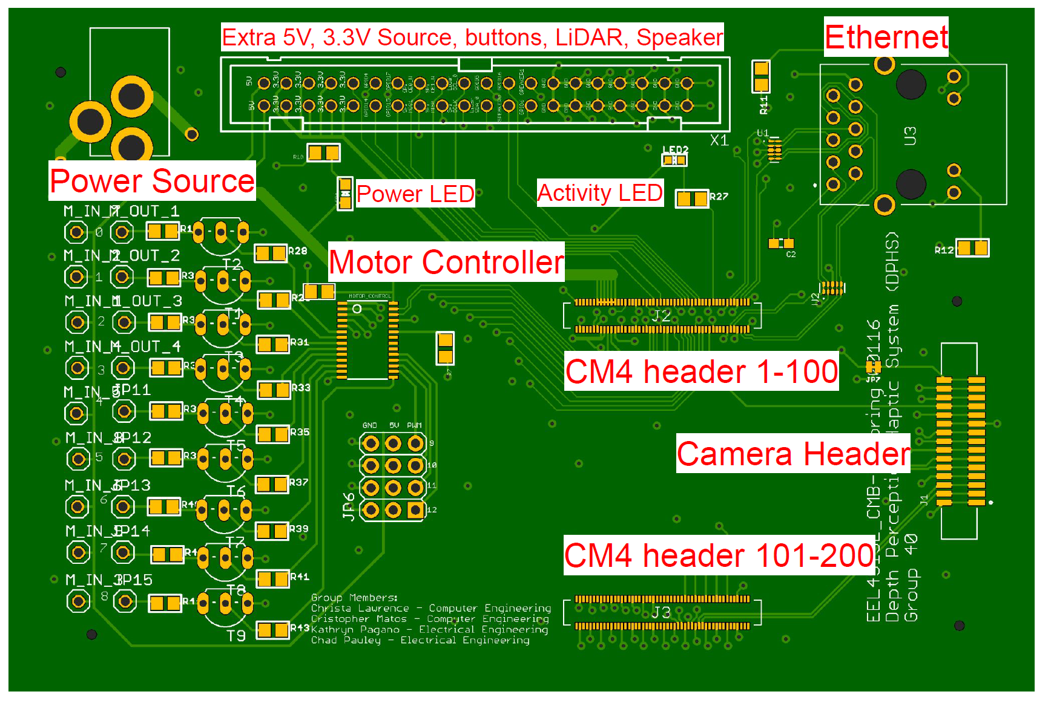
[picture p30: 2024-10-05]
CAD Image 1.PNG

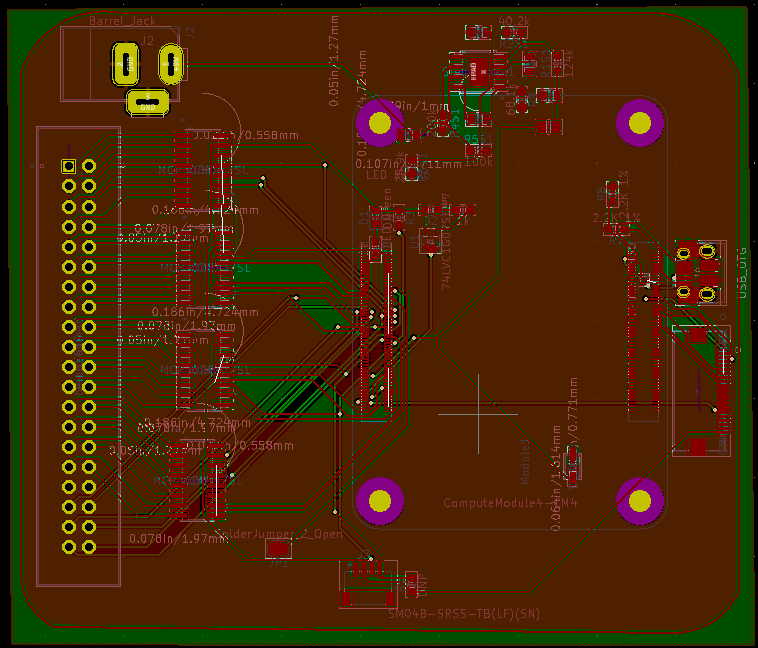
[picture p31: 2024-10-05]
Additional_Files/board.PNG

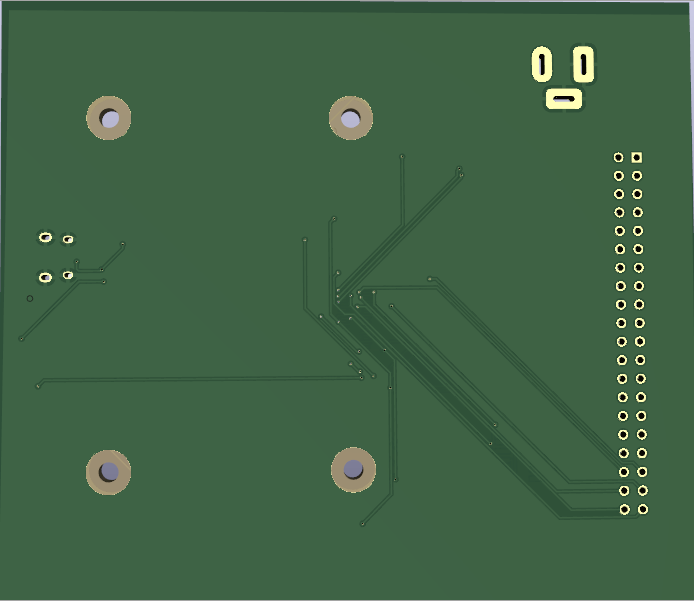
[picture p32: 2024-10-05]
Additional_Files/board 3d back.PNG

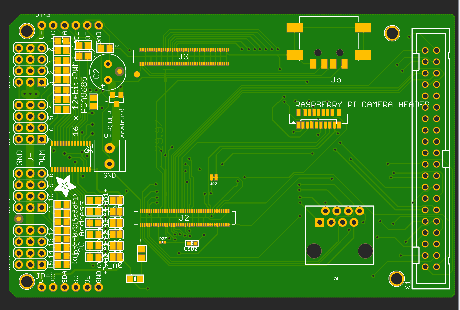
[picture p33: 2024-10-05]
Additional_Files/top 3D.PNG

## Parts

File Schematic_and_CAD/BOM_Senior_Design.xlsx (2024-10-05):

BOM for Senior_Design PCB
Description: This PCB is intended to act as a carryout board (like a motherboard) for the Raspberry Pi Compute Module 4 (CM4).
Item # | Ref Des | Qty | Stock | Manufacturer | Mfg Part # | Description/Value | Website
1 | R1N R2, R3, R4, R5, R6, R8, R9 | 8 | 4556 | TE Connectivity Passive Product | 352210KJT | 10k Resistors | https://www.digikey.com/en/products/detail/te-connectivity-passive-product/352210KJT/5244972
2 | PCA9685 | 1 | 474 | NXP Semiconductors | PCA9685PW,118 | 16 Channel 12-Bit PWM | https://www.mouser.com/ProductDetail/NXP-Semiconductors/PCA9685PW118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
3 | LED1, LED2 | 2 | 92453 | American Opto Plus LED | L513GD-B | Green LED | https://www.digikey.com/en/products/detail/american-opto-plus-led/L513GD-B/13556882
4 | R10, R11, R12, R13, R14, R15, R16, R17, R18, R19, R20, R21, R22, R23, R24, R25, R26 | 17 | 328 | TE Connectivity Passive Product | 3522220RJT | 220 ohm Resistor | https://www.digikey.co.uk/en/products/detail/te-connectivity-passive-product/3522220RJT/5245039
5 | C2 | 1 | N/A | N/A | N/A | Capacitor of about 600 uF. Ignore this part as the device still functions without it and will be soldered at a later time.
6 | Q1 | 1 | Unknown | Infineon | IRLML6401 | IRLML6401, voltage protection | https://www.mouser.com/ProductDetail/Infineon-IR/IRLML6401?qs=Gkr2N%2F2q3o14NhVCfm2QfQ%3D%3D
7 | U$47 | 1 | 91289 | CUI Devices | PJ-102A | Power Jack | https://www.digikey.com/en/products/detail/cui-devices/PJ-102A/275425
8 | R27 | 1 | 4531809 | YAGEO | RC0805FR-071KL | 1K resistor | https://www.digikey.com/en/products/detail/yageo/RC0805FR-071KL/727444
9 | 2540- | 1 | 4606240 | THD | THD-20-R | 40 pin (20x2) pin header, male | https://www.toby.co.uk/board-to-board-pcb-connectors/254mm-headers/thd-valcon-2.54mm-pitch-dual-row-pin-header/THD-20-R/
10 | 52559-1592 | 1 | 310 | Molex | 52271-1579 | Raspberry Pi Camera Header (15 pin) | https://sg.rs-online.com/web/p/fpc-connectors/6706827
11 | J2+, J3+ | 2 | 11020 | Hirose Electric Co Ltd | DF40C-100DS-0.4V(51) | CONN RCPT 100POS 0.4MM SMD GOLD | https://www.integrated-circuit.com/products-detail/DF40C-100DS-0.4V%2851%29/EIS-1228627.html
Minor modification to the circuit will be needed if item #6 cannot be obtained.

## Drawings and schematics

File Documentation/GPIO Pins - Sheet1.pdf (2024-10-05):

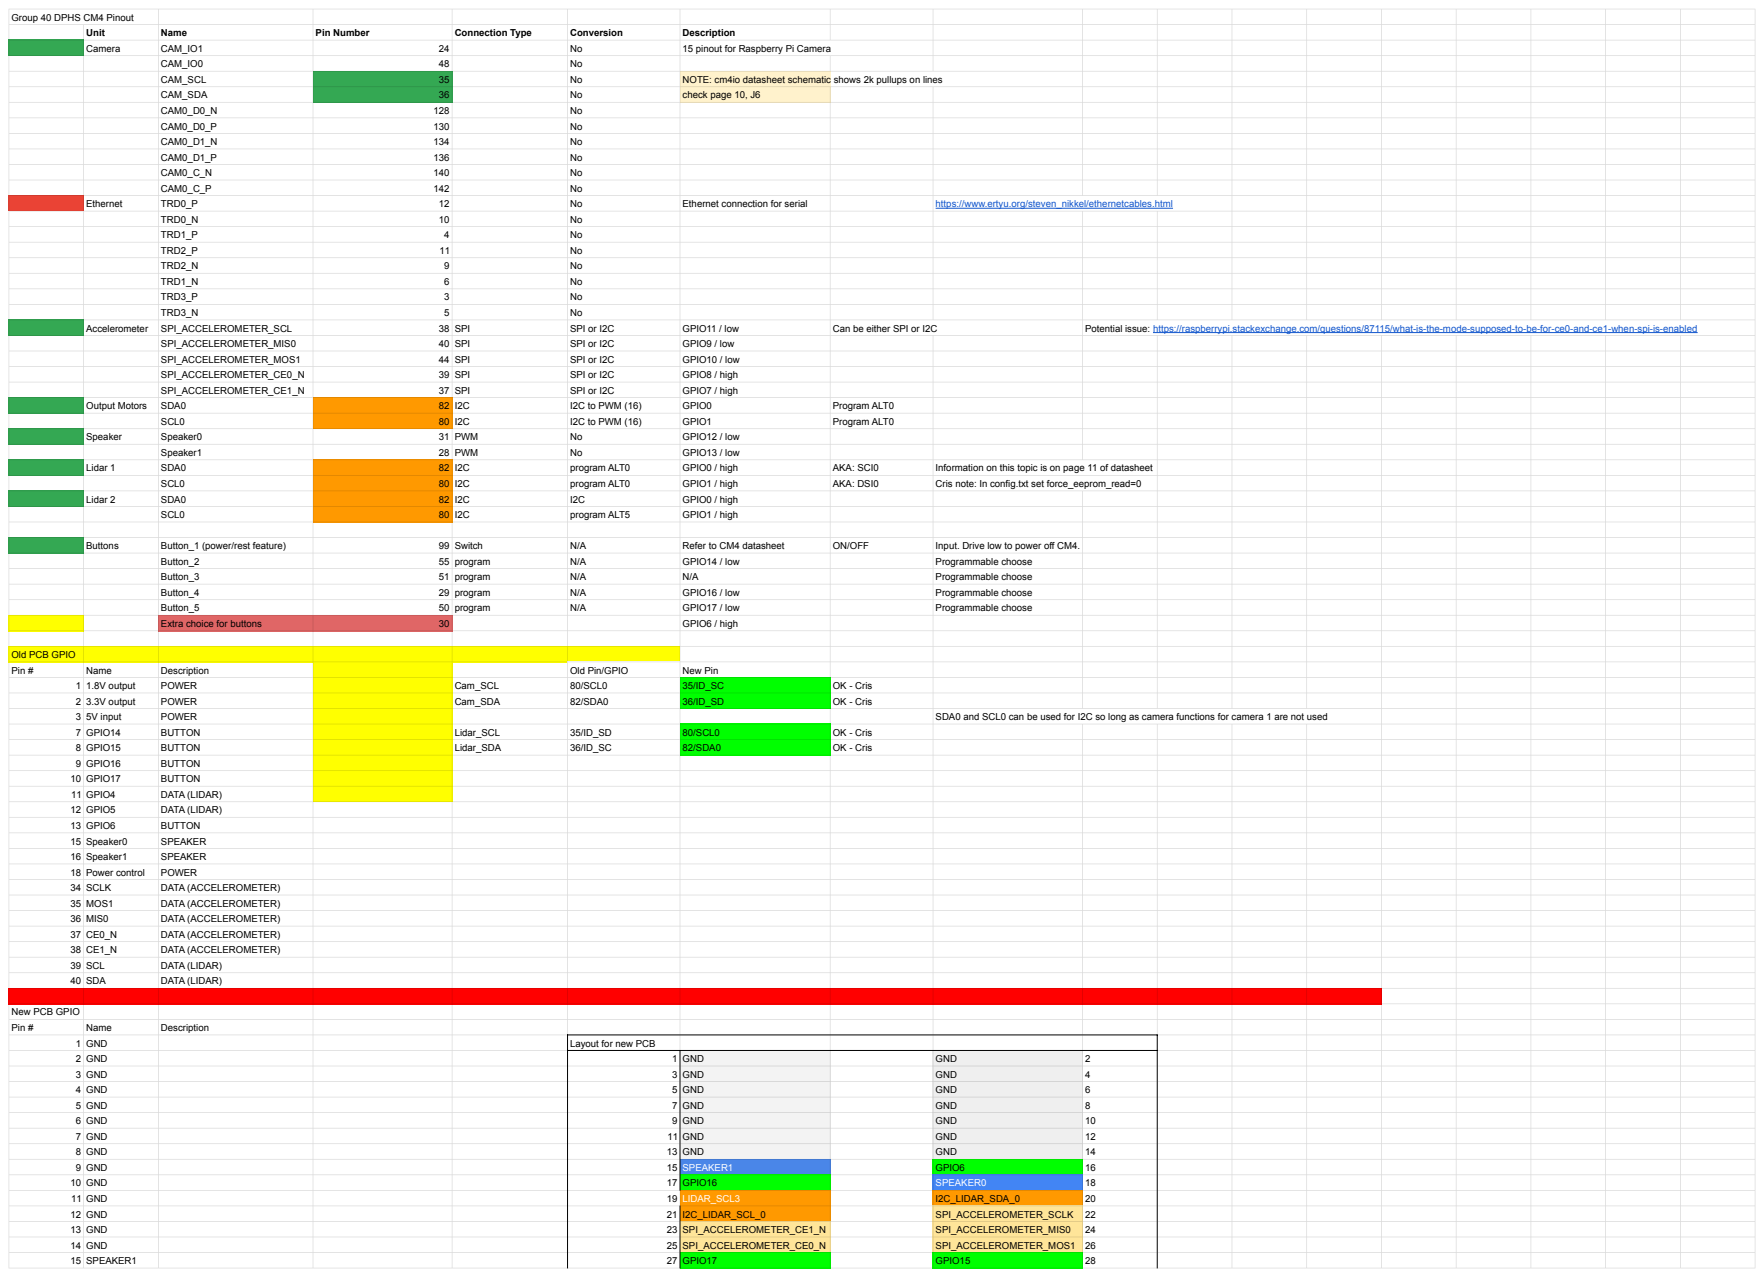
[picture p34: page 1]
Group 40 DPHS CM4 Pinout Unit; Name; Pin Number; Connection Type; Conversion; Description Camera; CAM_IO1; 15 pinout for Raspberry Pi Camera CAM_IO0; No CAM_SCL; NOTE: cm4io datasheet schematic shows 2k pullups on lines CAM_SDA; check page 10, J6 CAM0_D0_N; No CAM0_D0_P; No CAM0_D1_N; No CAM0_D1_P; No CAM0_C_N; No CAM0_C_P; No Ethernet; TRD0_P; Ethernet connection for serial; https://www.ertyu.org/steven_nikkel/ethernetcables.html; TRD0_N; TRD1_P; TRD2_P; TRD2_N; TRD1_N; TRD3_P; TRD3_N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

Old PCB GPIO

New PCB GPIO

2 GND 3 GND 4 GND 5 GND 6 GND 7 GND 8 GND 9 GND 10 GND 11 GND 12 GND 13 GND 14 GND 15 SPEAKER1 | 1 3 5 7 9 11 13 15 17 19 21 23 25 27 | GND GND GND GND GND GND GND | GND GND GND GND GND GND GND | 2 4 6 8 10 12 14

SPEAKER1 | GPIO6 | 16
GPIO16 | SPEAKER0 | 18
LIDAR_SCL3 I2C_LIDAR_SCL_0 | I2C_LIDAR_SDA_0 | 20
SPI_ACCELEROMETER_SCLK | 22
SPI_ACCELEROMETER_CE1_N SPI_ACCELEROMETER_CE0_N | SPI_ACCELEROMETER_MIS0 SPI_ACCELEROMETER_MOS1 | 24 26

GPIO17 | GPIO15 | 28

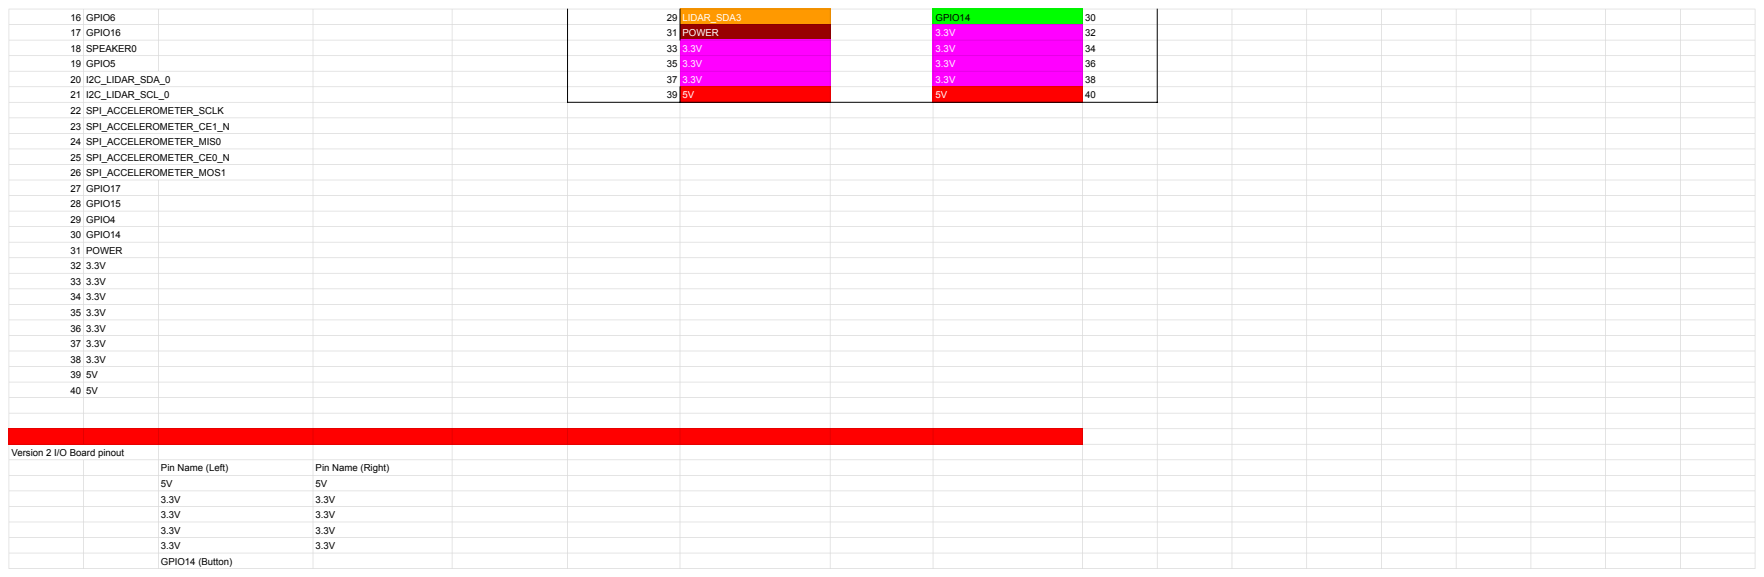
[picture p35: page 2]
16 GPIO6; LIDAR_SDA3; GPIO14; 17 GPIO16; POWER; 18 SPEAKER0; 19 GPIO5; 20 I2C_LIDAR_SDA_0; 21 I2C_LIDAR_SCL_0; 22 SPI_ACCELEROMETER_SCLK; 23 SPI_ACCELEROMETER_CE1_N; 24 SPI_ACCELEROMETER_MIS0; 25 SPI_ACCELEROMETER_CE0_N; 26 SPI_ACCELEROMETER_MOS1; 27 GPIO17; 28 GPIO15; 29 GPIO4; 30 GPIO14; 31 POWER; Version 2 I/O Board pinout; Pin Name (Left); Pin Name (Right); 3.3V GPIO14 (Button)

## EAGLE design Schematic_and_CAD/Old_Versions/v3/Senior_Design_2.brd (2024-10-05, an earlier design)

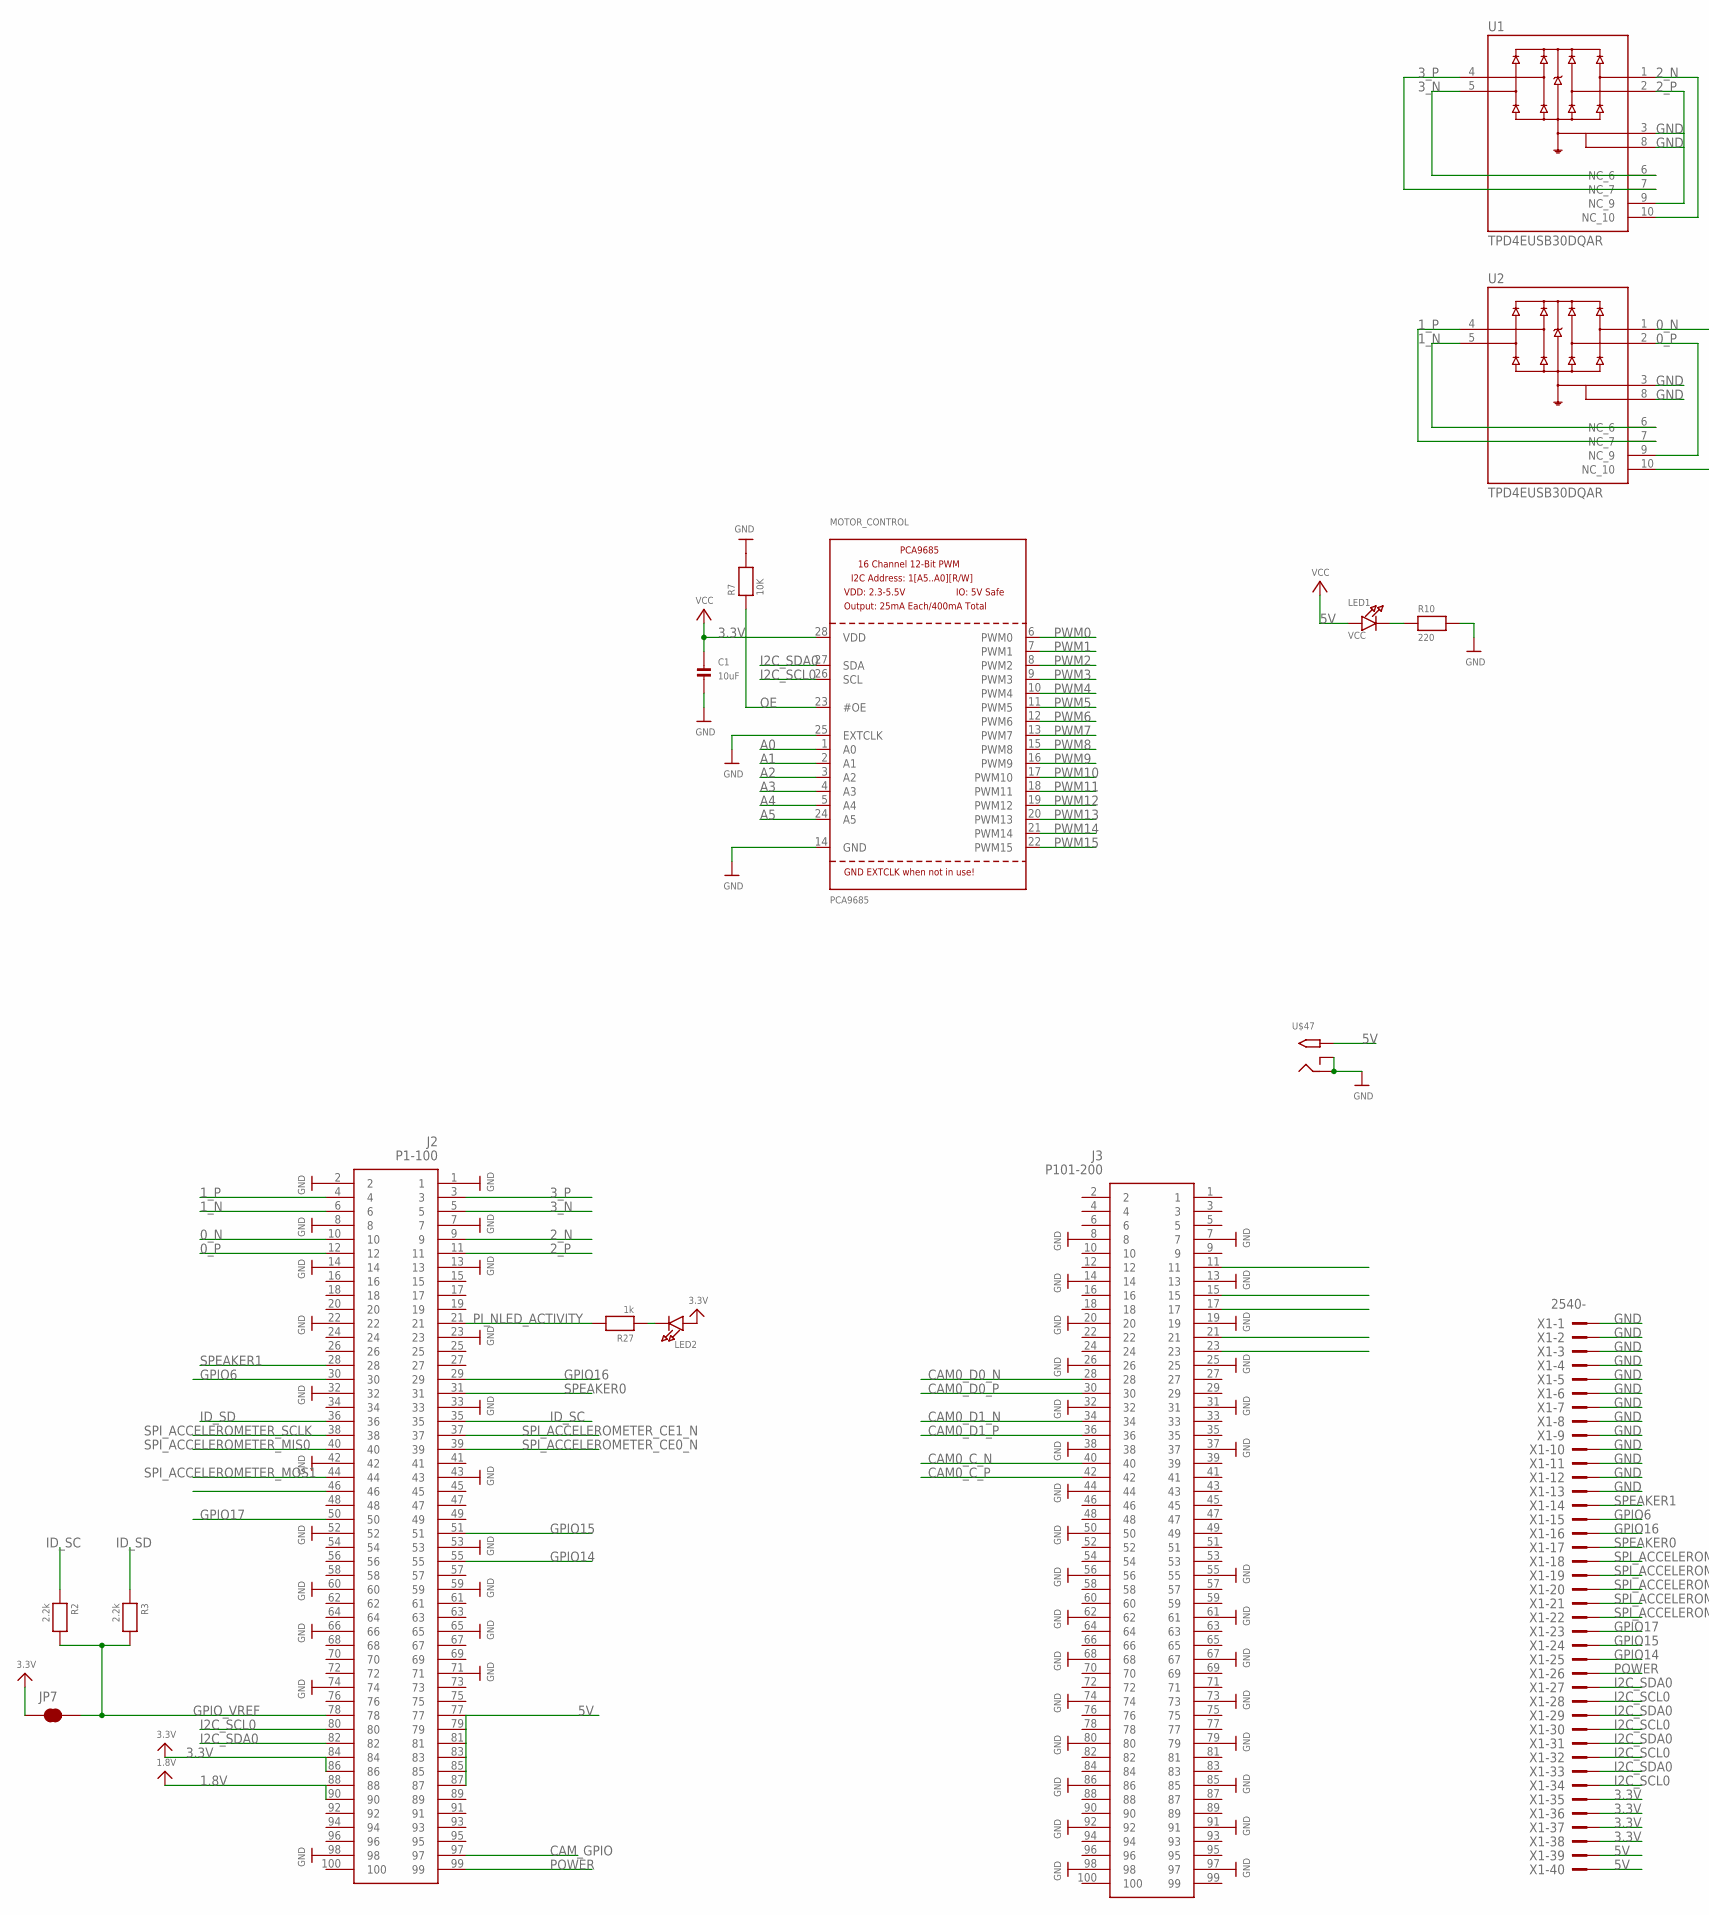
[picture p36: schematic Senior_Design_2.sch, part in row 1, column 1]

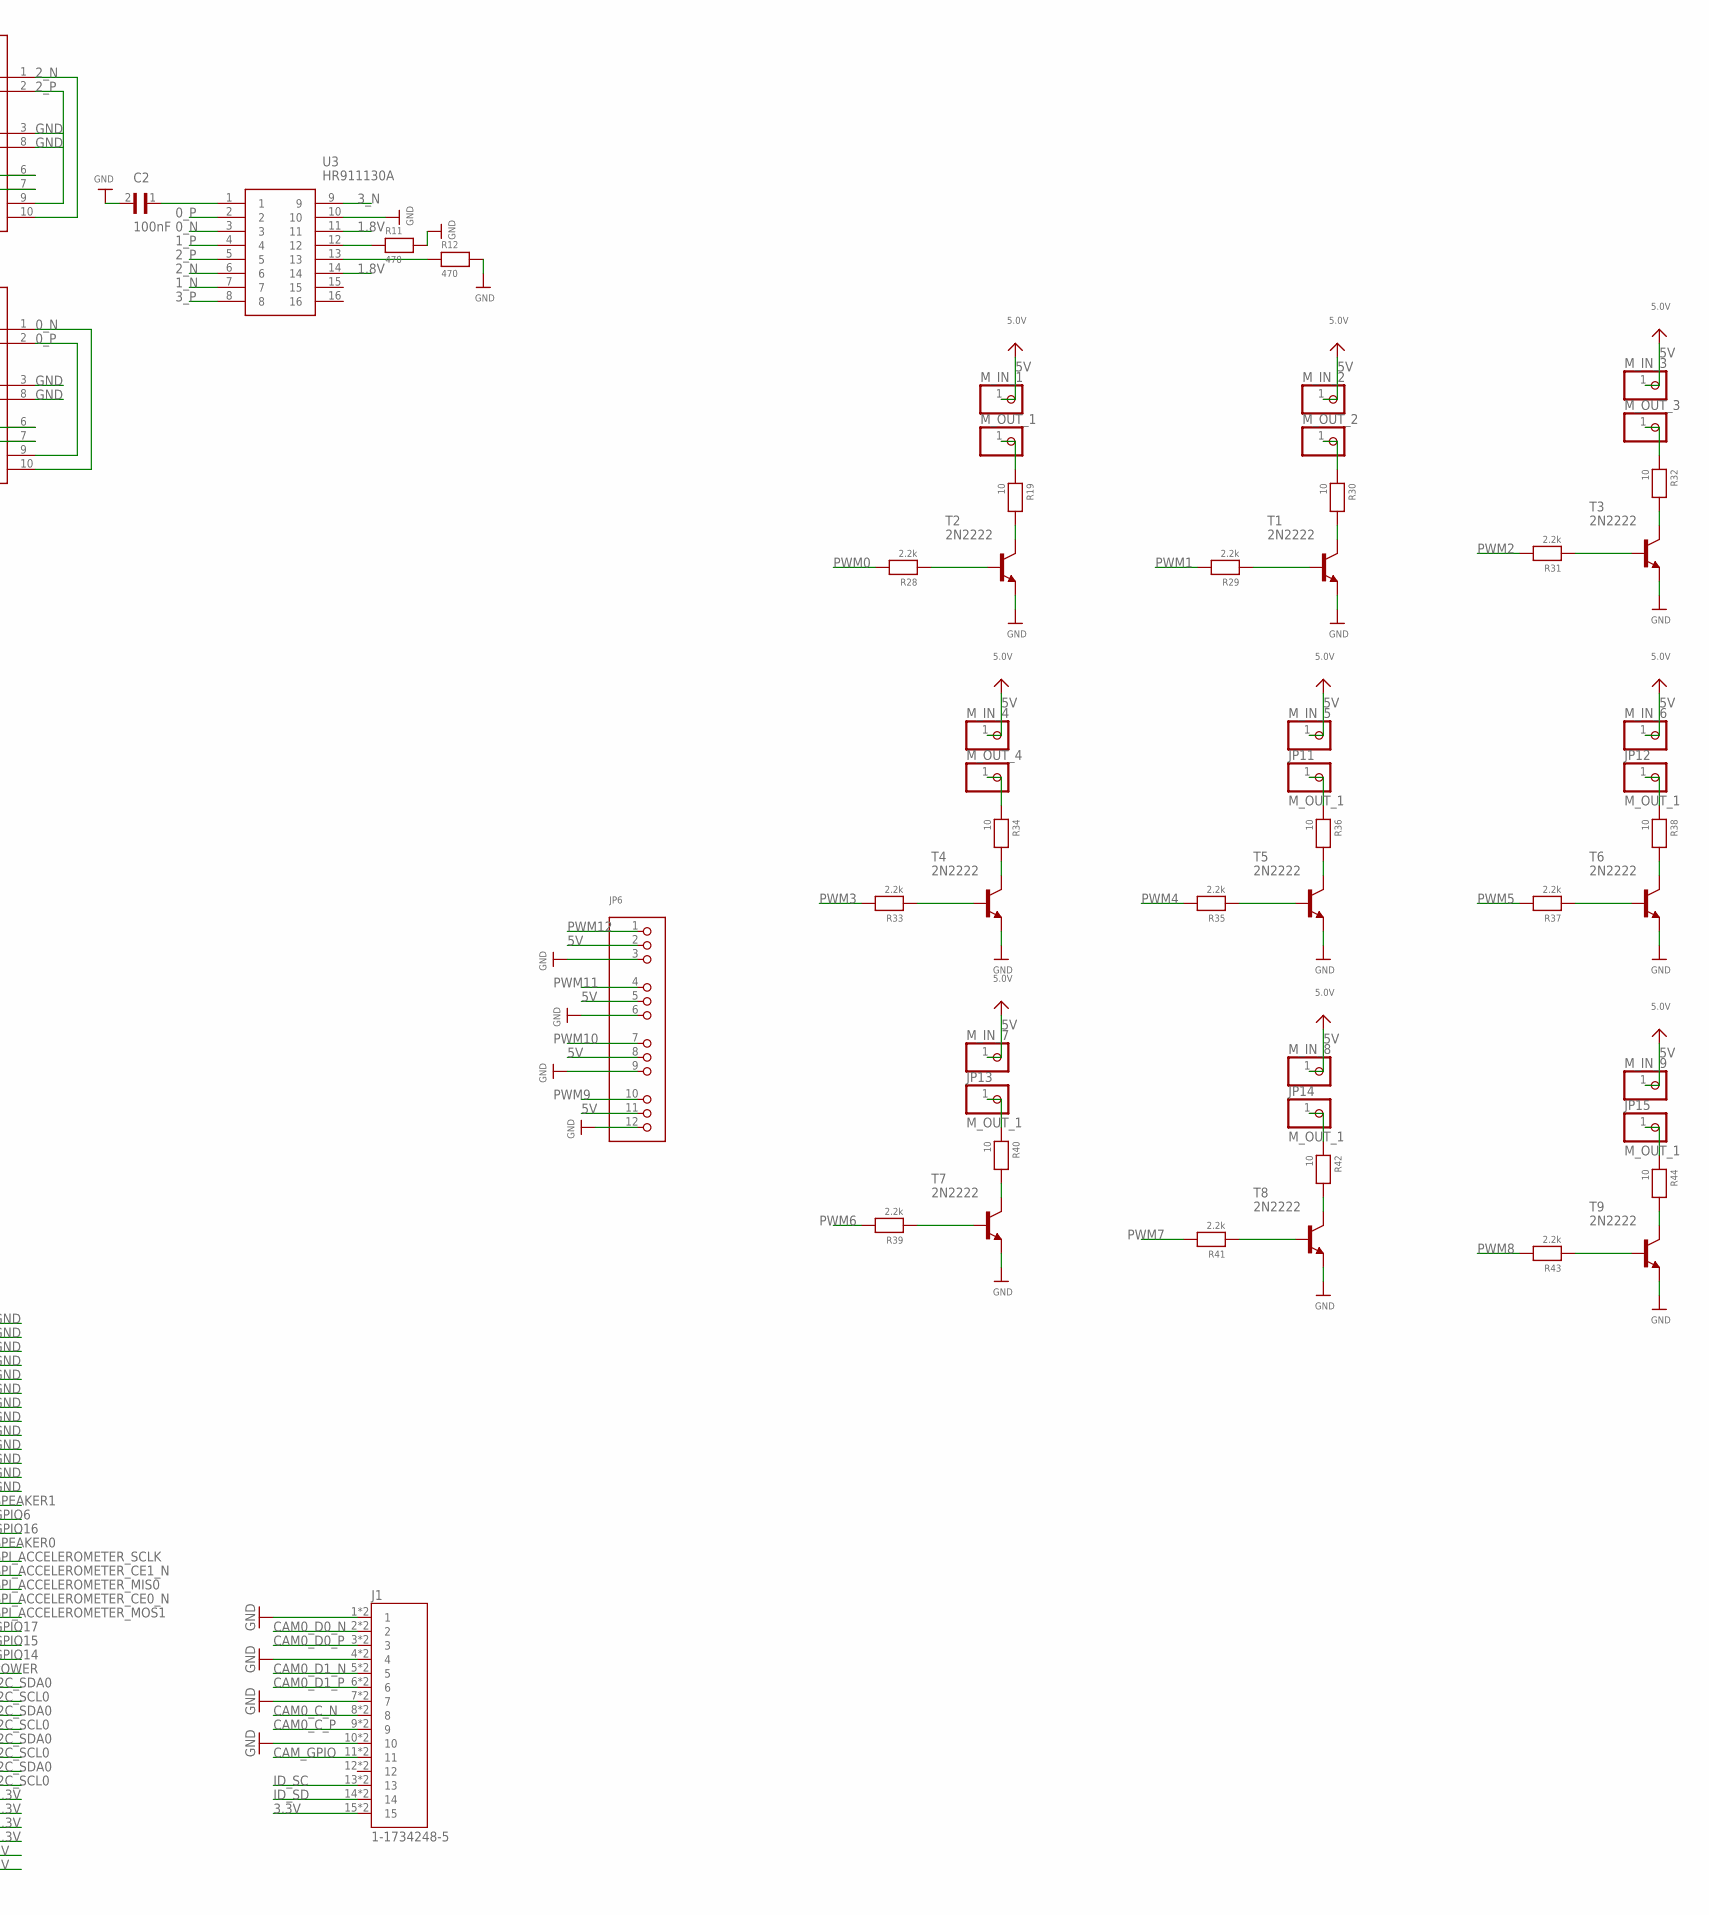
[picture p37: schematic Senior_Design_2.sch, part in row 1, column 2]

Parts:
C1: 10uF; 0805@1
C2: 100nF; CAPC1608X90
J1: 1-1734248-5; TE_1-1734248-5
J2: P1-100; DF40C100DS04V51; MPN MCW0406MD1003BP100
J3: P101-200; DF40C100DS04V51
JP6: HEADER-3X04; 3X04
JP7: JUMPER-SMT_2_NC_TRACE_NO-SILK; SMT-JUMPER_2_NC_TRACE_NO-SILK
JP11, JP12, JP13, JP14, JP15: M_OUT_1; 1X01
LED1: VCC; CHIPLED_0805
LED2: LED0603; CHIPLED_0603; MPN LS Q976-NR-1
MOTOR_CONTROL: PCA9685; TSSOP28
M_IN_1, M_IN_2, M_IN_3, M_IN_4, M_IN_5, M_IN_6, M_IN_7, M_IN_8, M_IN_9: PINHD-1X1; 1X01
M_OUT_1, M_OUT_2, M_OUT_3, M_OUT_4: PINHD-1X1; 1X01
R2, R3, R28, R29, R31, R33, R35, R37, R39, R41, R43: 2.2k; 0805
R7: 10K; 0805
R10: 220; 0805
R11, R12: 470; 0805
R19, R30, R32, R34, R36, R38, R40, R42, R44: 10; 0805
R27: 1k; 0805
T1, T2, T3, T4, T5, T6, T7, T8, T9: 2N2222; TO92-EBC-OVAL
U1, U2: TPD4EUSB30DQAR; IC_TPD4EUSB30DQAR
U3: HR911130A
U$47: 2.1MMJACKTHM; PJ-102A
X1: 2540-; PAK100/2500-40

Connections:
0_N: J2.10, U2.1 (D1+), U2.10 (NC_10), U3.3
0_P: J2.12, U2.2 (D1-), U2.9 (NC_9), U3.2
1.8V: J2.88, J2.90, U3.11, U3.14
1_N: J2.6, U2.5 (D2-), U2.6 (NC_6), U3.7
1_P: J2.4, U2.4 (D2+), U2.7 (NC_7), U3.4
2_N: J2.9, U1.1 (D1+), U1.10 (NC_10), U3.6
2_P: J2.11, U1.2 (D1-), U1.9 (NC_9), U3.5
3.3V: C1.1, J1.15, J1.15_1 (15), J2.84, J2.86, JP7.1, LED2.A, MOTOR_CONTROL.28 (VDD), X1.35, X1.36, X1.37, X1.38
3_N: J2.5, U1.5 (D2-), U1.6 (NC_6), U3.9
3_P: J2.3, U1.4 (D2+), U1.7 (NC_7), U3.8
5V: J2.77, J2.79, J2.81, J2.83, J2.85, J2.87, JP6.2, JP6.5, JP6.8, JP6.11, LED1.A, M_IN_1.1, M_IN_2.1, M_IN_3.1, M_IN_4.1, M_IN_5.1, M_IN_6.1, M_IN_7.1, M_IN_8.1, M_IN_9.1, U$47.TIP, X1.39, X1.40
A0: MOTOR_CONTROL.1 (A0)
A1: MOTOR_CONTROL.2 (A1)
A2: MOTOR_CONTROL.3 (A2)
A3: MOTOR_CONTROL.4 (A3)
A4: MOTOR_CONTROL.5 (A4)
A5: MOTOR_CONTROL.24 (A5)
CAM0_C_N: J1.8, J1.8_1 (8), J3.40
CAM0_C_P: J1.9, J1.9_1 (9), J3.42
CAM0_D0_N: J1.2, J1.2_1 (2), J3.28
CAM0_D0_P: J1.3, J1.3_1 (3), J3.30
CAM0_D1_N: J1.5, J1.5_1 (5), J3.34
CAM0_D1_P: J1.6, J1.6_1 (6), J3.36
CAM_GPIO: J1.11, J1.11_1 (11), J2.97
GND: C1.2, C2.2, J1.1, J1.1_1 (1), J1.4, J1.4_1 (4), J1.7, J1.7_1 (7), J1.10, J1.10_1 (10), J2.1, J2.2, J2.7, J2.8, J2.13, J2.14, J2.22, J2.23, J2.32, J2.33, J2.42, J2.43, J2.52, J2.53, J2.59, J2.60, J2.65, J2.66, J2.71, J2.74, J2.98, J3.7, J3.8, J3.13, J3.14, J3.19, J3.20, J3.25, J3.26, J3.31, J3.32, J3.37, J3.38, J3.44, J3.50, J3.55, J3.56, J3.61, J3.62, J3.67, J3.68, J3.73, J3.74, J3.79, J3.80, J3.85, J3.86, J3.91, J3.92, J3.97, J3.98, JP6.3, JP6.6, JP6.9, JP6.12, MOTOR_CONTROL.14 (GND), MOTOR_CONTROL.25 (EXTCLK), R7.2, R10.2, R11.2, R12.2, T1.E, T2.E, T3.E, T4.E, T5.E, T6.E, T7.E, T8.E, T9.E, U1.3 (GND_3), U1.8 (GND_8), U2.3 (GND_3), U2.8 (GND_8), U3.10, U$47.RING, U$47.RING_SW, X1.1, X1.2, X1.3, X1.4, X1.5, X1.6, X1.7, X1.8, X1.9, X1.10, X1.11, X1.12, X1.13
GPIO6: J2.30, X1.15
GPIO14: J2.55, X1.25
GPIO15: J2.51, X1.24
GPIO16: J2.29, X1.16
GPIO17: J2.50, X1.23
GPIO_VREF: J2.78, JP7.2, R2.2, R3.2
I2C_SCL0: J2.80, MOTOR_CONTROL.26 (SCL), X1.28, X1.30, X1.32, X1.34
I2C_SDA0: J2.82, MOTOR_CONTROL.27 (SDA), X1.27, X1.29, X1.31, X1.33
ID_SC: J1.13, J1.13_1 (13), J2.35, R2.1
ID_SD: J1.14, J1.14_1 (14), J2.36, R3.1
unnamed: LED1.C, R10.1
unnamed: C2.1, U3.1
unnamed: R11.1, U3.12
unnamed: R12.1, U3.13
unnamed: R19.2, T2.C
unnamed: LED2.C, R27.1
unnamed: R28.1, T2.B
unnamed: M_OUT_1.1, R19.1
unnamed: R29.1, T1.B
unnamed: R30.2, T1.C
unnamed: M_OUT_2.1, R30.1
unnamed: R31.1, T3.B
unnamed: R32.2, T3.C
unnamed: M_OUT_3.1, R32.1
unnamed: R33.1, T4.B
unnamed: R34.2, T4.C
unnamed: M_OUT_4.1, R34.1
unnamed: R35.1, T5.B
unnamed: R36.2, T5.C
unnamed: JP11.1, R36.1
unnamed: R37.1, T6.B
unnamed: R38.2, T6.C
unnamed: JP12.1, R38.1
unnamed: R39.1, T7.B
unnamed: R40.2, T7.C
unnamed: JP13.1, R40.1
unnamed: R41.1, T8.B
unnamed: R42.2, T8.C
unnamed: JP14.1, R42.1
unnamed: R43.1, T9.B
unnamed: R44.2, T9.C
unnamed: JP15.1, R44.1
OE: MOTOR_CONTROL.23 (#OE), R7.1
PI_NLED_ACTIVITY: J2.21, R27.2
POWER: J2.99, X1.26
PWM0: MOTOR_CONTROL.6 (PWM0), R28.2
PWM1: MOTOR_CONTROL.7 (PWM1), R29.2
PWM2: MOTOR_CONTROL.8 (PWM2), R31.2
PWM3: MOTOR_CONTROL.9 (PWM3), R33.2
PWM4: MOTOR_CONTROL.10 (PWM4), R35.2
PWM5: MOTOR_CONTROL.11 (PWM5), R37.2
PWM6: MOTOR_CONTROL.12 (PWM6), R39.2
PWM7: MOTOR_CONTROL.13 (PWM7), R41.2
PWM8: MOTOR_CONTROL.15 (PWM8), R43.2
PWM9: JP6.10, MOTOR_CONTROL.16 (PWM9)
PWM10: JP6.7, MOTOR_CONTROL.17 (PWM10)
PWM11: JP6.4, MOTOR_CONTROL.18 (PWM11)
PWM12: JP6.1, MOTOR_CONTROL.19 (PWM12)
PWM13: MOTOR_CONTROL.20 (PWM13)
PWM14: MOTOR_CONTROL.21 (PWM14)
PWM15: MOTOR_CONTROL.22 (PWM15)
SPEAKER0: J2.31, X1.17
SPEAKER1: J2.28, X1.14
SPI_ACCELEROMETER_CE0_N: J2.39, X1.21
SPI_ACCELEROMETER_CE1_N: J2.37, X1.19
SPI_ACCELEROMETER_MIS0: J2.40, X1.20
SPI_ACCELEROMETER_MOS1: J2.44, X1.22
SPI_ACCELEROMETER_SCLK: J2.38, X1.18

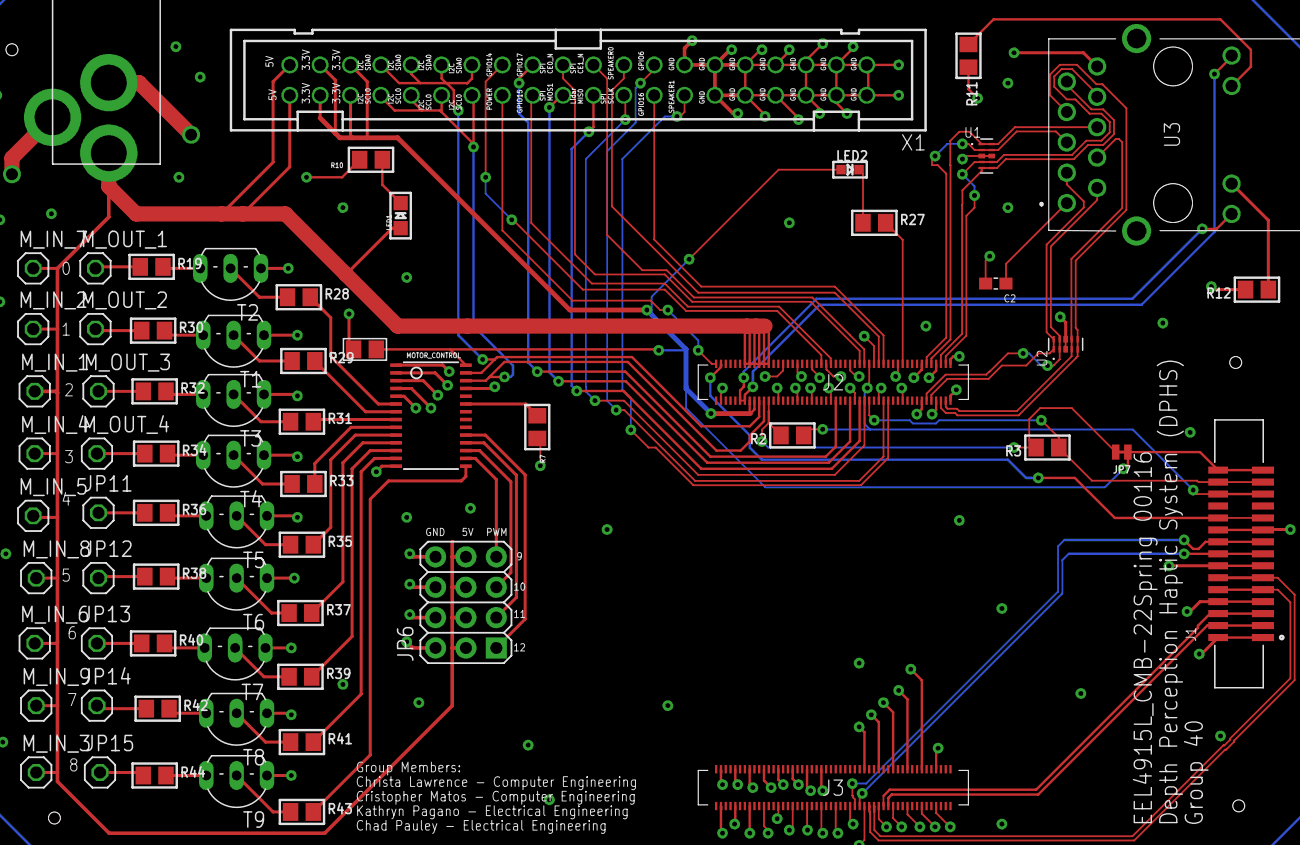
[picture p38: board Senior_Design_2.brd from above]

Board: 2 copper layers, 67 parts (0 on the bottom side), 84 nets.

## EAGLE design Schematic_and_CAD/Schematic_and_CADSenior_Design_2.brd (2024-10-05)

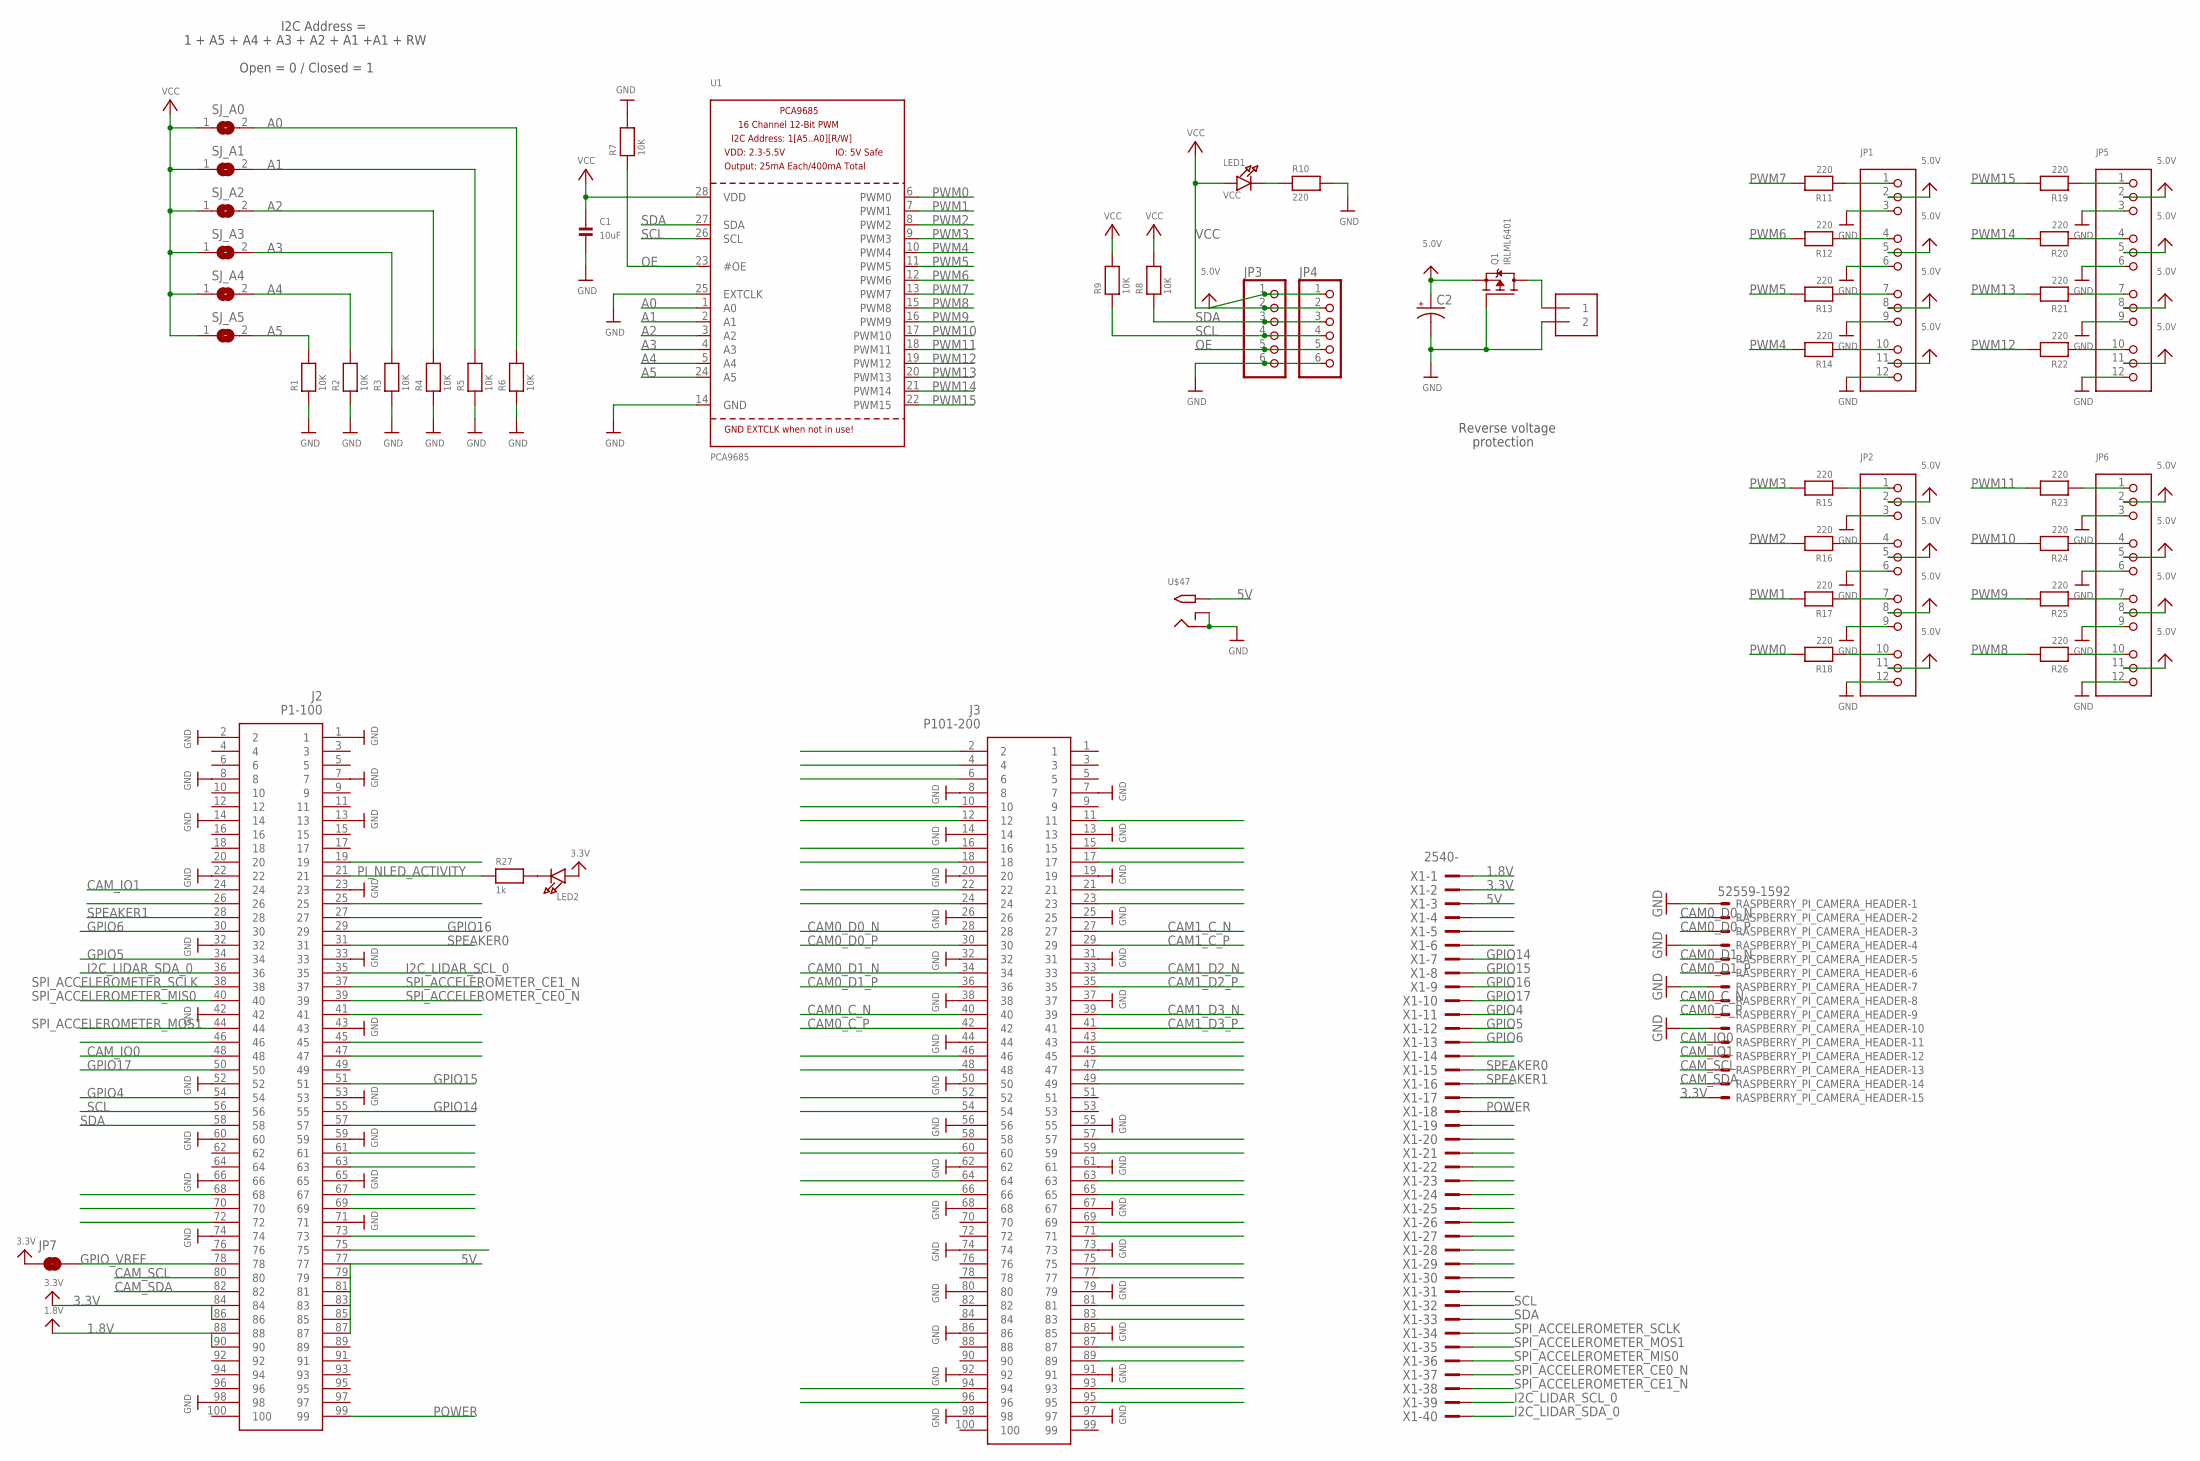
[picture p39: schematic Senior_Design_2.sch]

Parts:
C1: 10uF; 0805@1
C2: CPOL-USE3.5-8; E3,5-8
J1: TERMBLOCK_1X2-3.5MM; 1X2-3.5MM
J2: P1-100; DF40C100DS04V51; MPN MCW0406MD1003BP100
J3: P101-200; DF40C100DS04V51
JP1, JP2, JP5, JP6: HEADER-3X04; 3X04
JP3, JP4: PINHD-1X6CB; 1X06-CLEANBIG
JP7: JUMPER-SMT_2_NC_TRACE_NO-SILK; SMT-JUMPER_2_NC_TRACE_NO-SILK
LED1: VCC; CHIPLED_0805
LED2: LED0603; CHIPLED_0603; MPN LS Q976-NR-1
Q1: IRLML6401; SOT23-WIDE
R1, R2, R3, R4, R5, R6, R7, R8, R9: 10K; 0805
R10, R11, R12, R13, R14, R15, R16, R17, R18, R19, R20, R21, R22, R23, R24, R25, R26: 220; 0805
R27: 1k; _0402MP; MPN ERJ-8ENF1001V
RASPBERRY_PI_CAMERA_HEADER: 52559-1592
SJ_A0, SJ_A1, SJ_A2, SJ_A3, SJ_A4, SJ_A5: SOLDERJUMPERREFLOW_NOPASTE; SOLDERJUMPER_REFLOW_NOPASTE
U1: PCA9685; TSSOP28
U$47: 2.1MMJACKTHM; PJ-102A
X1: 2540-; PAK100/2500-40

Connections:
1.8V: J2.88, J2.90, X1.1
3.3V: J2.84, J2.86, JP7.1, LED2.A, RASPBERRY_PI_CAMERA_HEADER.15, X1.2
5.0V: C2.+, JP1.2, JP1.5, JP1.8, JP1.11, JP2.2, JP2.5, JP2.8, JP2.11, JP3.1, JP4.1, JP5.2, JP5.5, JP5.8, JP5.11, JP6.2, JP6.5, JP6.8, JP6.11, Q1.2 (S)
5V: J2.77, J2.79, J2.81, J2.83, J2.85, J2.87, U$47.TIP, X1.3
A0: R6.2, SJ_A0.2, U1.1 (A0)
A1: R5.2, SJ_A1.2, U1.2 (A1)
A2: R4.2, SJ_A2.2, U1.3 (A2)
A3: R3.2, SJ_A3.2, U1.4 (A3)
A4: R2.2, SJ_A4.2, U1.5 (A4)
A5: R1.2, SJ_A5.2, U1.24 (A5)
CAM0_C_N: J3.40, RASPBERRY_PI_CAMERA_HEADER.8
CAM0_C_P: J3.42, RASPBERRY_PI_CAMERA_HEADER.9
CAM0_D0_N: J3.28, RASPBERRY_PI_CAMERA_HEADER.2
CAM0_D0_P: J3.30, RASPBERRY_PI_CAMERA_HEADER.3
CAM0_D1_N: J3.34, RASPBERRY_PI_CAMERA_HEADER.5
CAM0_D1_P: J3.36, RASPBERRY_PI_CAMERA_HEADER.6
CAM1_C_N: J3.27
CAM1_C_P: J3.29
CAM1_D2_N: J3.33
CAM1_D2_P: J3.35
CAM1_D3_N: J3.39
CAM1_D3_P: J3.41
CAM_IO0: J2.48, RASPBERRY_PI_CAMERA_HEADER.11
CAM_IO1: J2.24, RASPBERRY_PI_CAMERA_HEADER.12
CAM_SCL: J2.80, RASPBERRY_PI_CAMERA_HEADER.13
CAM_SDA: J2.82, RASPBERRY_PI_CAMERA_HEADER.14
GND: C1.2, C2.-, J1.2, J2.1, J2.2, J2.7, J2.8, J2.13, J2.14, J2.22, J2.23, J2.32, J2.33, J2.42, J2.43, J2.52, J2.53, J2.59, J2.60, J2.65, J2.66, J2.71, J2.74, J2.98, J3.7, J3.8, J3.13, J3.14, J3.19, J3.20, J3.25, J3.26, J3.31, J3.32, J3.37, J3.38, J3.44, J3.50, J3.55, J3.56, J3.61, J3.62, J3.67, J3.68, J3.73, J3.74, J3.79, J3.80, J3.85, J3.86, J3.91, J3.92, J3.97, J3.98, JP1.3, JP1.6, JP1.9, JP1.12, JP2.3, JP2.6, JP2.9, JP2.12, JP3.6, JP4.6, JP5.3, JP5.6, JP5.9, JP5.12, JP6.3, JP6.6, JP6.9, JP6.12, Q1.1 (G), R1.1, R2.1, R3.1, R4.1, R5.1, R6.1, R7.2, R10.2, RASPBERRY_PI_CAMERA_HEADER.1, RASPBERRY_PI_CAMERA_HEADER.4, RASPBERRY_PI_CAMERA_HEADER.7, RASPBERRY_PI_CAMERA_HEADER.10, U1.14 (GND), U1.25 (EXTCLK), U$47.RING, U$47.RING_SW
GPIO4: J2.54, X1.11
GPIO5: J2.34, X1.12
GPIO6: J2.30, X1.13
GPIO14: J2.55, X1.7
GPIO15: J2.51, X1.8
GPIO16: J2.29, X1.9
GPIO17: J2.50, X1.10
GPIO_VREF: J2.78, JP7.2
I2C_LIDAR_SCL_0: J2.35, X1.39
I2C_LIDAR_SDA_0: J2.36, X1.40
unnamed: LED1.C, R10.1
unnamed: JP1.4, R12.1
unnamed: JP1.1, R11.1
unnamed: JP1.7, R13.1
unnamed: JP1.10, R14.1
unnamed: JP2.1, R15.1
unnamed: JP2.4, R16.1
unnamed: JP2.7, R17.1
unnamed: JP2.10, R18.1
unnamed: JP6.10, R26.1
unnamed: JP6.7, R25.1
unnamed: JP6.4, R24.1
unnamed: JP6.1, R23.1
unnamed: JP5.10, R22.1
unnamed: JP5.7, R21.1
unnamed: JP5.4, R20.1
unnamed: JP5.1, R19.1
unnamed: LED2.C, R27.2
OE: JP3.5, JP4.5, R7.1, U1.23 (#OE)
PI_NLED_ACTIVITY: J2.21, R27.1
POWER: J2.99, X1.18
PWM0: R18.2, U1.6 (PWM0)
PWM1: R17.2, U1.7 (PWM1)
PWM2: R16.2, U1.8 (PWM2)
PWM3: R15.2, U1.9 (PWM3)
PWM4: R14.2, U1.10 (PWM4)
PWM5: R13.2, U1.11 (PWM5)
PWM6: R12.2, U1.12 (PWM6)
PWM7: R11.2, U1.13 (PWM7)
PWM8: R26.2, U1.15 (PWM8)
PWM9: R25.2, U1.16 (PWM9)
PWM10: R24.2, U1.17 (PWM10)
PWM11: R23.2, U1.18 (PWM11)
PWM12: R22.2, U1.19 (PWM12)
PWM13: R21.2, U1.20 (PWM13)
PWM14: R20.2, U1.21 (PWM14)
PWM15: R19.2, U1.22 (PWM15)
PWRIN: J1.1, Q1.3 (D)
SCL: J2.56, JP3.4, JP4.4, R9.1, U1.26 (SCL), X1.32
SDA: J2.58, JP3.3, JP4.3, R8.1, U1.27 (SDA), X1.33
SPEAKER0: J2.31, X1.15
SPEAKER1: J2.28, X1.16
SPI_ACCELEROMETER_CE0_N: J2.39, X1.37
SPI_ACCELEROMETER_CE1_N: J2.37, X1.38
SPI_ACCELEROMETER_MIS0: J2.40, X1.36
SPI_ACCELEROMETER_MOS1: J2.44, X1.35
SPI_ACCELEROMETER_SCLK: J2.38, X1.34
VCC: C1.1, JP3.2, JP4.2, LED1.A, R8.2, R9.2, SJ_A0.1, SJ_A1.1, SJ_A2.1, SJ_A3.1, SJ_A4.1, SJ_A5.1, U1.28 (VDD)

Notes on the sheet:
Reverse voltage
protection
1 + A5 + A4 + A3 + A2 + A1 +A1 + RW
I2C Address =
Open = 0 / Closed = 1

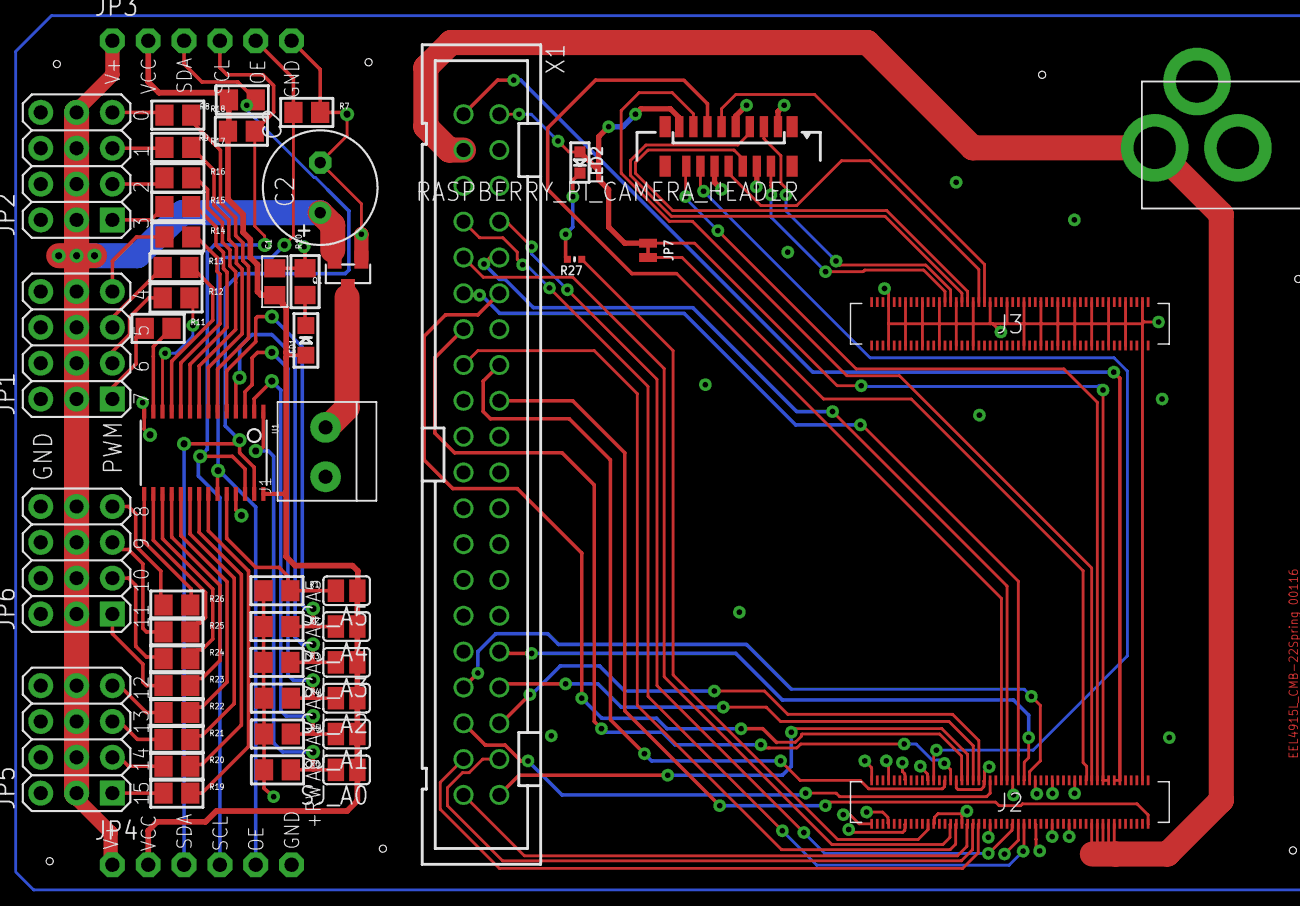
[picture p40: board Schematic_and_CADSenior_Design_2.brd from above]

Board: 2 copper layers, 52 parts (0 on the bottom side), 79 nets.

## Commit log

2024-10-05 BOM, Schematic, and CAD files.
    [BOM_Senior_Design.xlsx, Senior_Design_2.brd, Senior_Design_2.sch]
2024-10-05 Footprints
    The footprints used in the CAD Design
2024-10-05 Footprint Files
    May be missing some items required for brd file, discretion is advised.
2024-10-05 Eagle Library
    All footprints used in development. Some files may not be used or have been modified from the source. Use at own risk.

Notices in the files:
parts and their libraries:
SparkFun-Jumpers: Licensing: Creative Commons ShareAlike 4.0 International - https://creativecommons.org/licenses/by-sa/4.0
